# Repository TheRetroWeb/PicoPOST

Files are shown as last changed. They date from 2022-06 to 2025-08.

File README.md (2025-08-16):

# PicoPOST

> [!NOTE]
> You can get a quick summary from the blog post! [Introducing the PicoPOST - The Retro Web Blog](https://blog.theretroweb.com/2023/01/03/introducing-the-picopost/)

## Introduction

PicoPOST Logo

**PicoPOST** is a PC diagnostic card for systems with, at least, an 8-bit ISA slot. It's based around the Raspberry Pi
Pico, powered by an RP2040.

PicoPOST is designed to provide many additional benefits over the basic POST cards that are commonly available from
Chinese vendors on eBay and other sites.

This project is getting ready for public usage, with a few prototypes already in use for development purposes. More
information soon as it gets finalized.

## Implemented features

- Simple user interface, with a graphical monochrome 128x32 OLED display and a few buttons living on their own remote
  control
- Port 80h readout, with 4-place output history
- Port 90h readout, for IBM PS/2s
- Port 84h reaodut, for Compaq machines*
- Port 300h readout, for some EISA systems*
- Port 378h readout, for some Olivetti machines*
- More complete bus activity dumping facility
- Reset pulse detection
- +5V and +12V ~~and -12V~~ voltage monitor**
- Display is dimmed after 15s of inactivity to mitigate burn-in
- Flying Toasters! screensaver after 30s of inactivity on the main menu

> *: We don't have a specimen handy, so we need confirmation from someone else out there.\
> **: Negative voltages into a positive ADC is too much mental gymnastics without additional hardware

### Videos

We are slowly compiling a [YouTube playlist](https://www.youtube.com/playlist?list=PLejCJef6DKnVJob0ycztrpl9FoBufaOPA)
with a whole bunch of demonstration pieces, showing what the PicoPOST is capable of doing.\
Stay tuned for more content!

### Wishlist

New features have been implemented with the new rev 6 PCB and matching firmware.
- Full bus activity trace (HW OK, FW provisioned, but we need to make sure we are not missing data)
- Bus clock reader (HW OK, FW TBD)
- ... anything else, as long as the hardware allows it and someone implements it in firmware

## Building the firmware

### Automagically

We make use of Visual Studio Code and the official Raspberry Pi Pico extension for an easier life. When you first open
the project in VSCode, you will be prompted to install a few suggested extensions; accept the proposal and follow
on-screen instructions.

You should now be greeted by the CMake and Pi Pico sidebar panels. Use the CMake panel to switch between Debug or
Release builds, then refer to the Pico panel for building, uploading, and debugging the firmware.

It's already set up to probe for a compatible debugger via OpenOCD and gdbserver, and it works really well with our
official Raspberry Pi Debug Probe. I expect other SWD debuggers to work just as well (J-Link, STLink, ...).

### Manually

The firmware is built using the official Raspberry Pi RP2040 SDK. Follow the
[official documentation](https://github.com/raspberrypi/pico-sdk#quick-start-your-own-project) for setting it up.

The procedure is pretty straight-forward:
1. Clone the repo
   ```
   mkdir ~/repo
   cd ~/repo
   git clone https://github.com/TheRetroWeb/PicoPOST
   ```
2. Enter the repo and initialize it
   ```
   cd PicoPOST
   git submodule init
   git submodule update
   ```
3. Prepare the build system with CMake
   ```
   export PICO_SDK_PATH /path/to/pico/sdk
   cmake -DCMAKE_EXPORT_COMPILE_COMMANDS:BOOL=TRUE \
       -DCMAKE_BUILD_TYPE:STRING=Release \
       -DCMAKE_C_COMPILER:FILEPATH=/usr/bin/arm-none-eabi-gcc \
       -DCMAKE_CXX_COMPILER:FILEPATH=/usr/bin/arm-none-eabi-g++ \
       -S./firmware \
       -B./build \
       -G "Unix Makefiles"
   ```
4. Build the firmware
   ```
   cmake --build ./build --config Release --target all -j $(nproc)
   ```

### Customize the firmware

There are a couple of details you might want to tune at compile time. More specifically, you may want to better calibrate
the voltage monitor to show more accurate results.

In the primary `firmware\CMakeLists.txt` file, there are three variables you can set to skew the final ADC conversion result. These were added to account for resistor tolerances in the voltage divider circuits.
- `CALIBADJ_5V`, correction factor for the +5V rail
- `CALIBADJ_12V`, correction factor for the +12V rail

Calculating these factors is pretty straight forward:
- Install the default firmware
- Connect PicoPOST to your computer of choice with a known good power supply
- Enter `Voltage Monitor` mode
- Turn on the computer
- With a multimeter, measure the rail voltage as close as possible to PicoPOST
- Compute the required calibration factor by dividing the measured value with the one shown by PicoPOST
- Edit the `CALIBADJ` variable and build the firmware again

## Flashing the firmware

1. In order to load new firmware, the Pico must be booted into UF2 mode:
   - If the board is powered off, keep the BOOTSEL button pressed while plugging the USB cable into the Pico itself.
   - If the board is already powered, you can short the "Pico Reset" pins on the back of the card instead of removing the USB cable.
   - Alternatively, if the board is powered via USB from a PC with a data cable, you can move to the `Update FW` menu entry. By pressing Enter, the Pico will then be rebooted into UF2 mode automatically.
2. A mass storage device should be now mounted on your computer.
3. Drag and drop (or copy and paste) the `.uf2` firmware file into the device.
4. Once loaded, it will automatically restart and disconnect.
5. If all went well, you should now be greeted by the main menu on the OLED display.\
   You can verify the current firmware version by entering the `Info` page.

## Interested in helping?
- Submit issues and pull requests!
- Join us in the #picopost channel in [The Retro Web discord server](https://discord.gg/TdD4tqQ7fv)
- Join us and other developers of retro Pico hardware (such as PicoGUS and PicoMEM) in the [Retro Pico Hardware discord server](https://discord.gg/QBUkpPqFa5)

## Directories

```
datasheets/  Reference documentation for components used in the PicoPOST
firmware/    Source code for the PicoPOST firmware (written in C/C++ with the official Pico SDK)
pcb/         KiCad schematics and PCB design files
```

## License

The firmware portion of PicoPOST is licensed under the MIT license.\
The hardware portion of PicoPOST is licensed under the CERN OHL v2 Permissive license.

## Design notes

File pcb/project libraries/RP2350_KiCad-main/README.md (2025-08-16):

# RP2350_KiCad
Symbols, Footprints &amp; Models for the RP2350

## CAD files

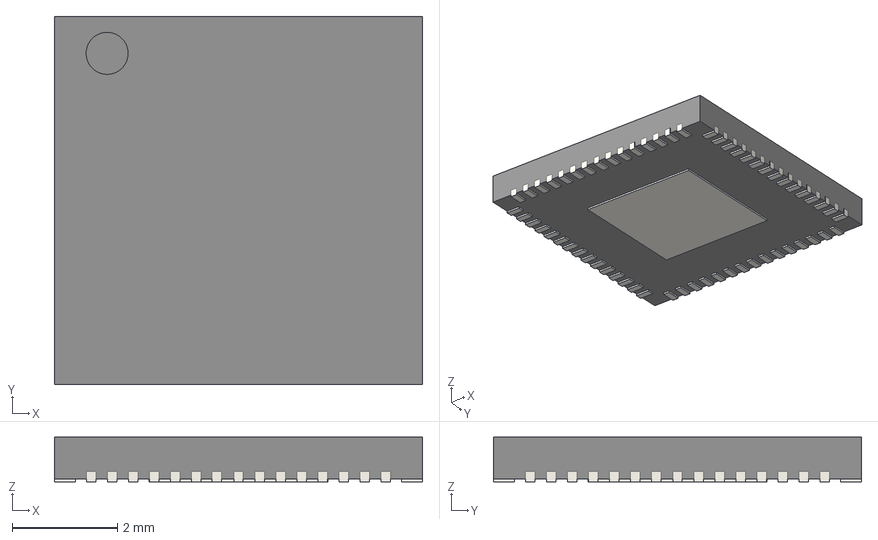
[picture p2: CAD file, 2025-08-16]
pcb/project libraries/RP2350_KiCad-main/RP2350A-QFN60.step
7.00 x 7.00 x 0.85 mm

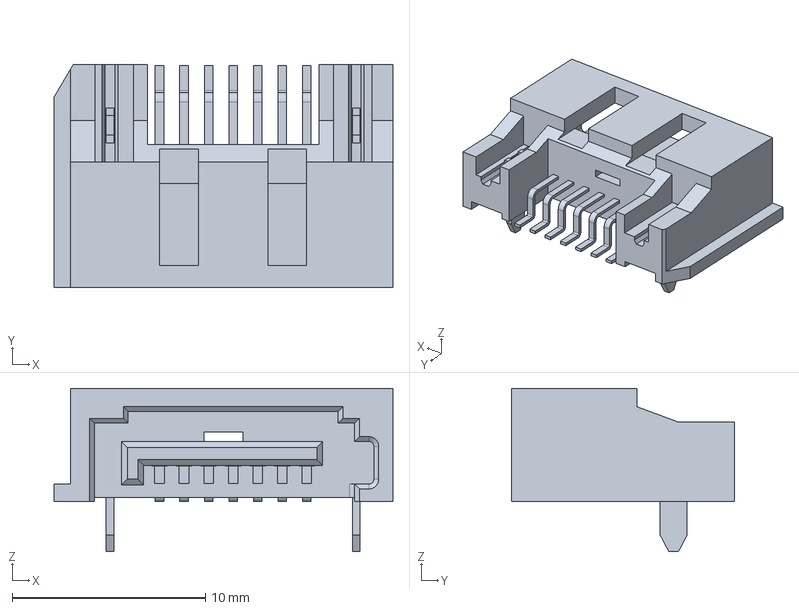
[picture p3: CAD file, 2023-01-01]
pcb/project libraries/eec.models/Molex_-_47080-4001.step
17.5 x 11.6 x 8.45 mm

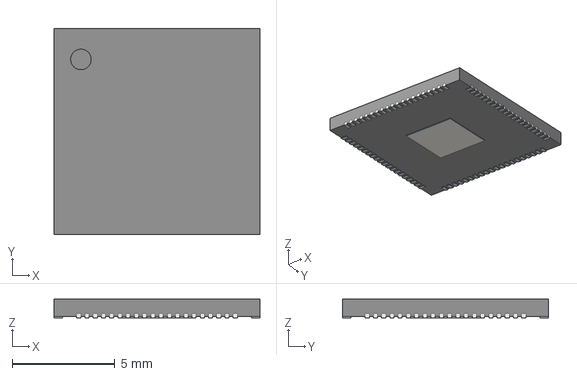
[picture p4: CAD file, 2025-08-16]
pcb/project libraries/RP2350_KiCad-main/RP2350B-QFN80.step
10.0 x 10.0 x 0.9 mm

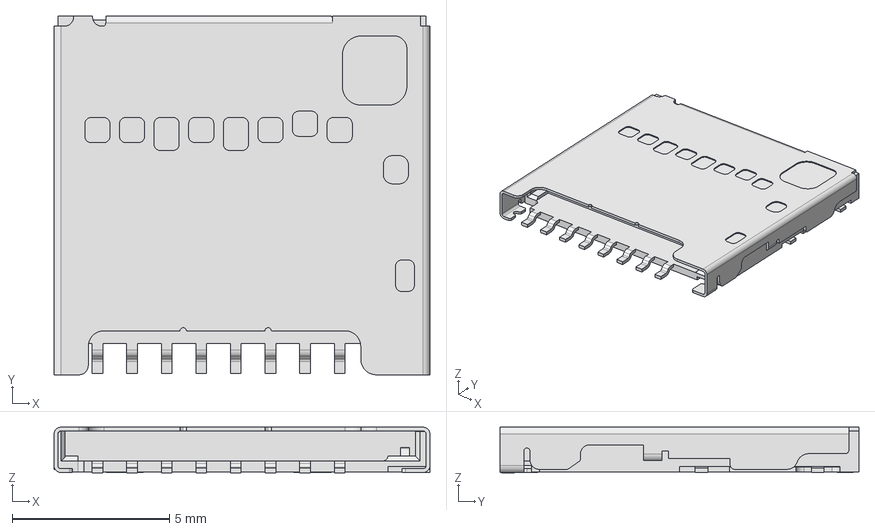
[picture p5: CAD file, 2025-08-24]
pcb/project libraries/1040310811.stp
11.9 x 11.4 x 1.45 mm

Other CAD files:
pcb/project libraries/eec.models/470804001.stp

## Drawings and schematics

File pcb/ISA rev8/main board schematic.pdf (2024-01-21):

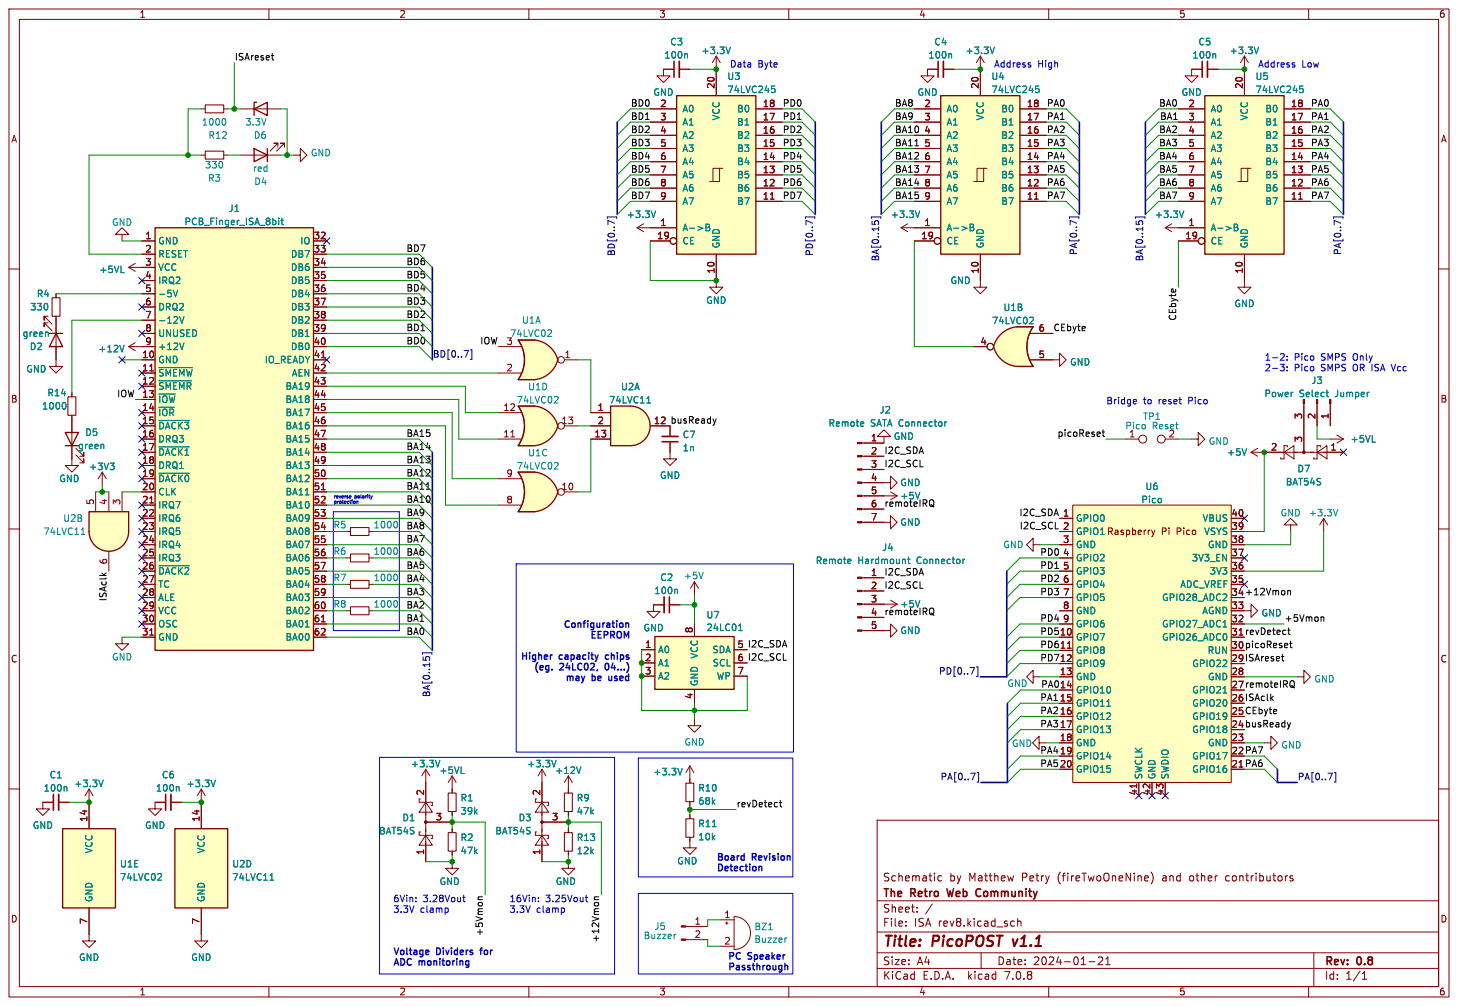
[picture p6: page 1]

J3 Power Select Jumper GND

Bridge to reset Pico Configuration EEPROM

J2 Remote SATA Connector GND GNDGND

Higher capacity chips
(eg. 24LC02, 04...) may be used

4 SDA 5 SCL 6 WP 7 VCC

Passthrough Board Revision Detection

Voltage Dividers for ADC monitoring

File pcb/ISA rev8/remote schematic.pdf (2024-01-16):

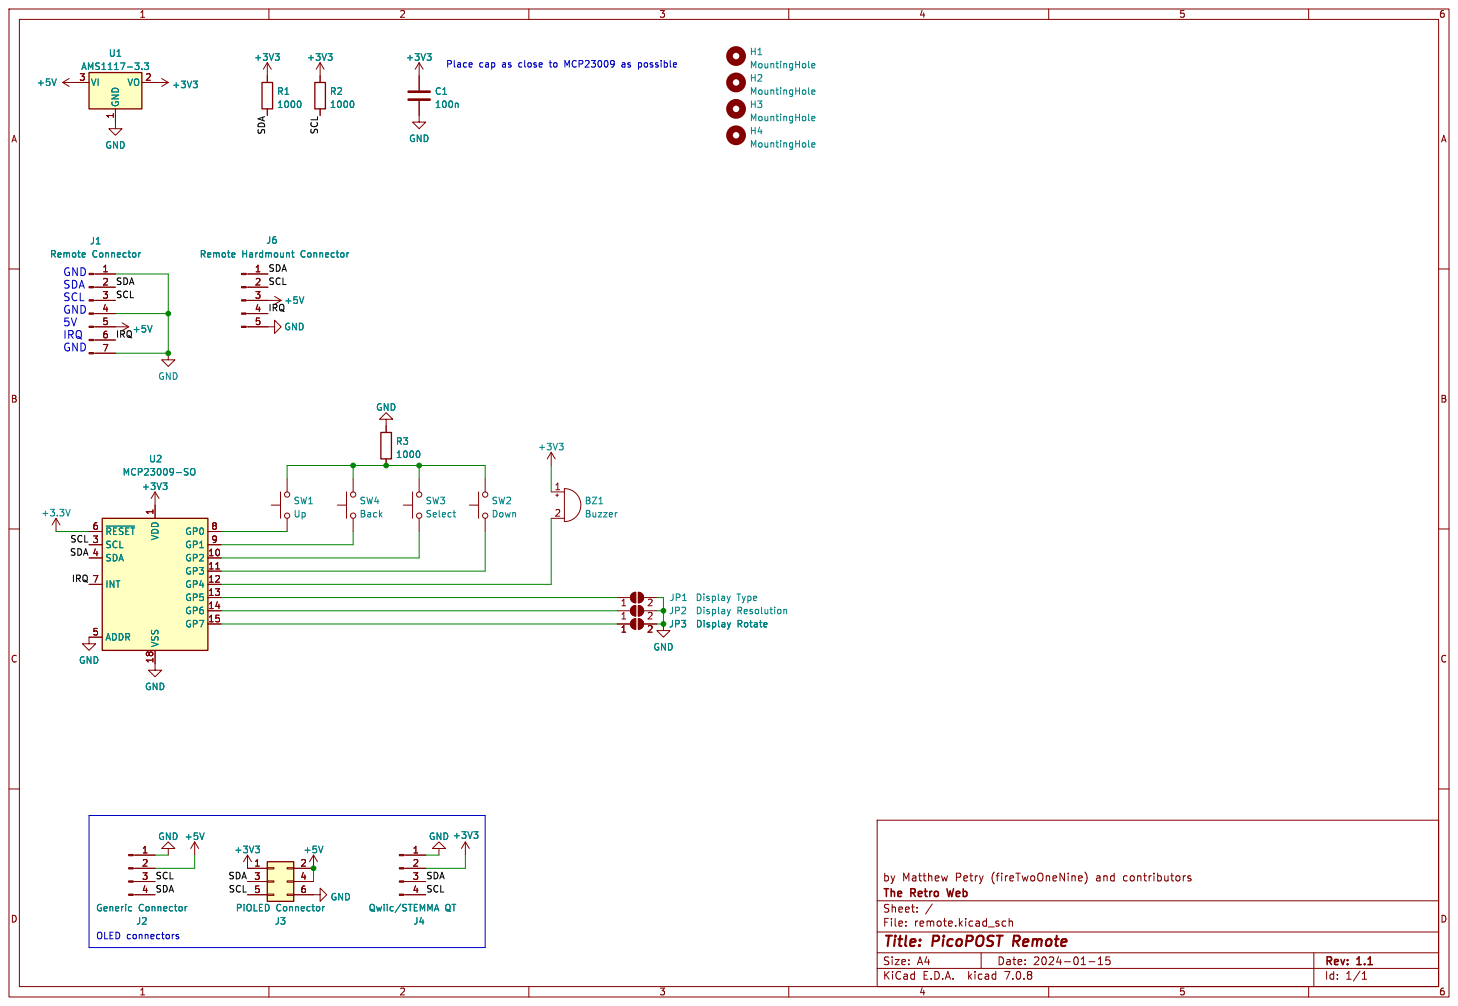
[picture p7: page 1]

1 VO 2 VI 3 U1 AMS1117-3.3 +5V GND GND

Place cap as close to MCP23009 as possible

1 GP2 10 GP3 11 GP4 12 GP5 13 GP6 14 GP7 15 VSS 18 SCL 3 SDA 4 ADDR 5 ~{RESET} 6

Id: 1/1 Title: PicoPOST Remote

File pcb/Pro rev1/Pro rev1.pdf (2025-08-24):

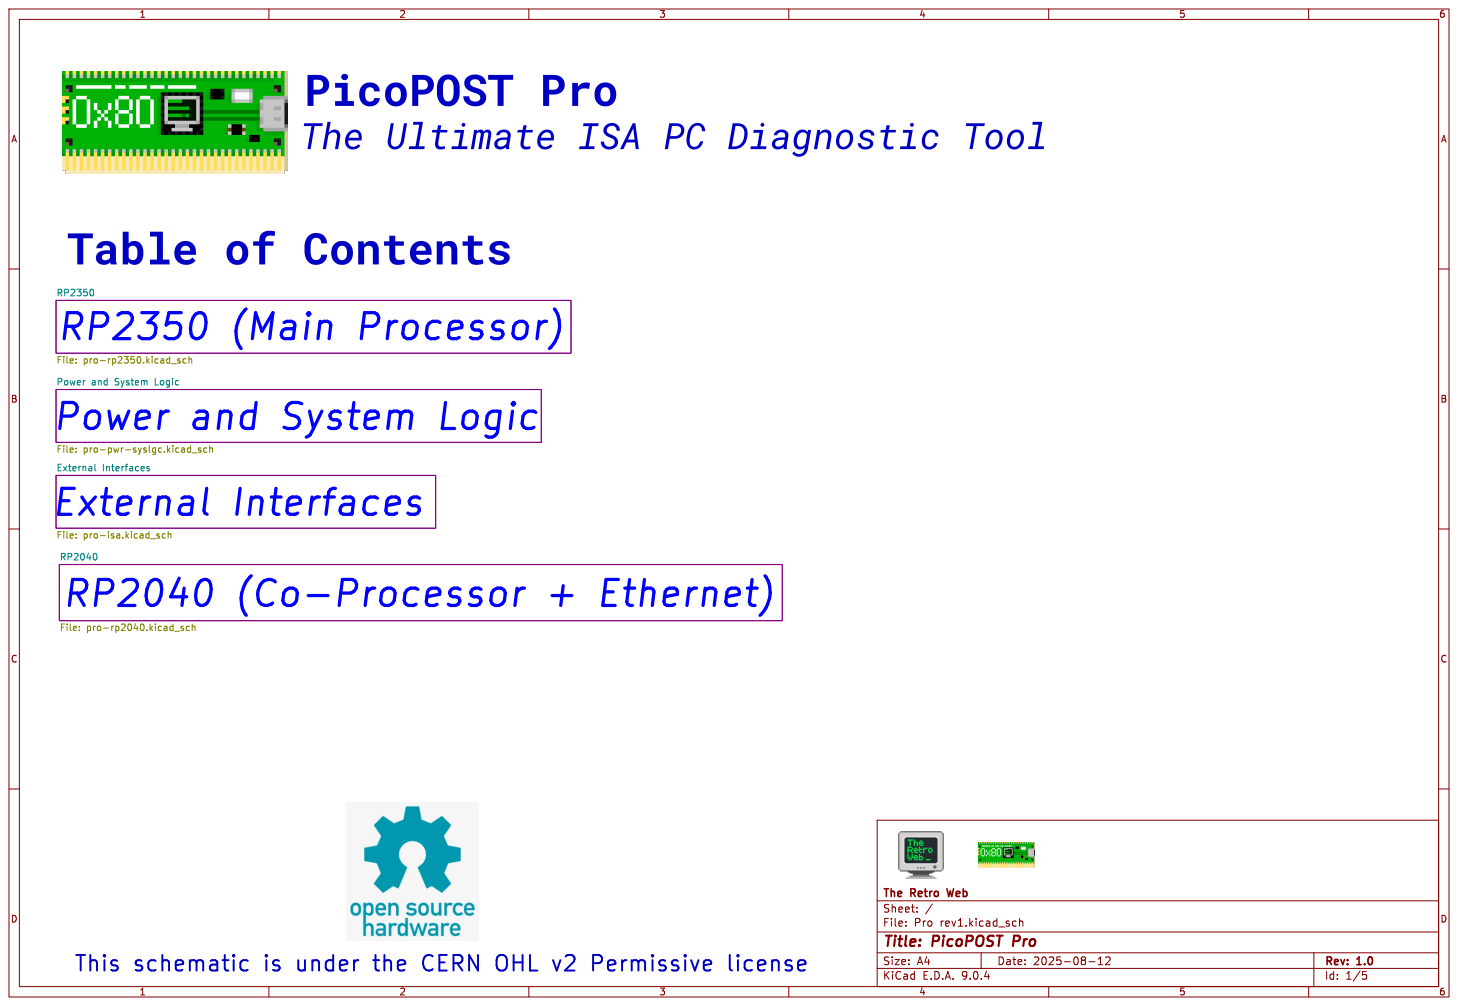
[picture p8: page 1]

Power and System Logic File: pro-pwr-syslgc.kicad_sch
Power and System Logic

External Interfaces File: pro-isa.kicad_sch
External Interfaces

Id: 1/5 Title: PicoPOST Pro

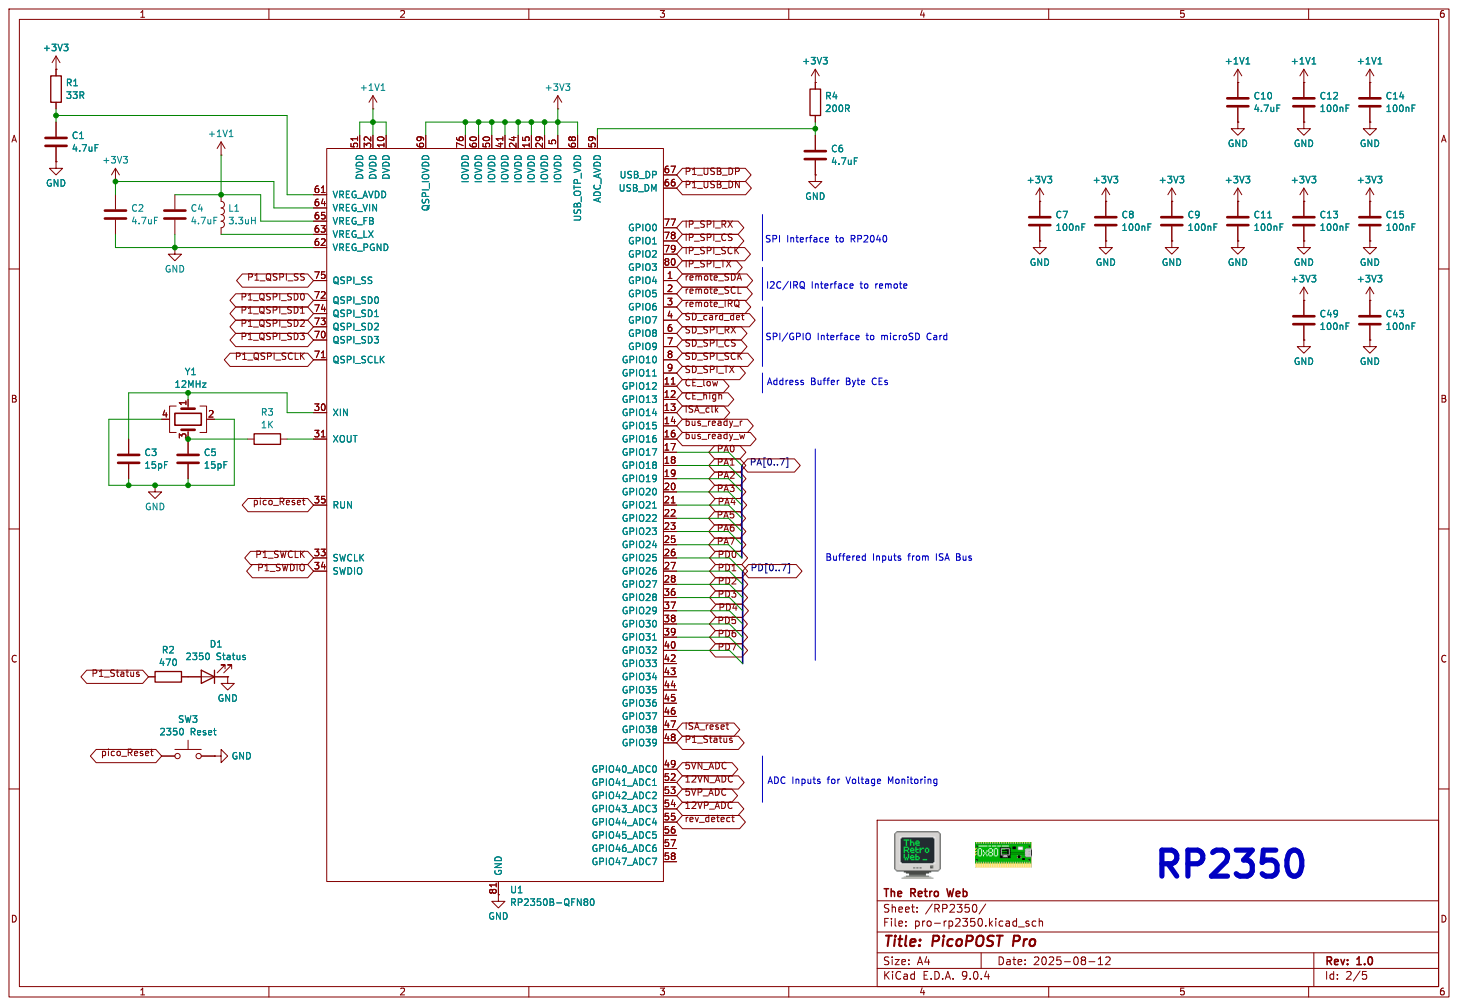
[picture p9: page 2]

Id: 2/5 Title: PicoPOST Pro

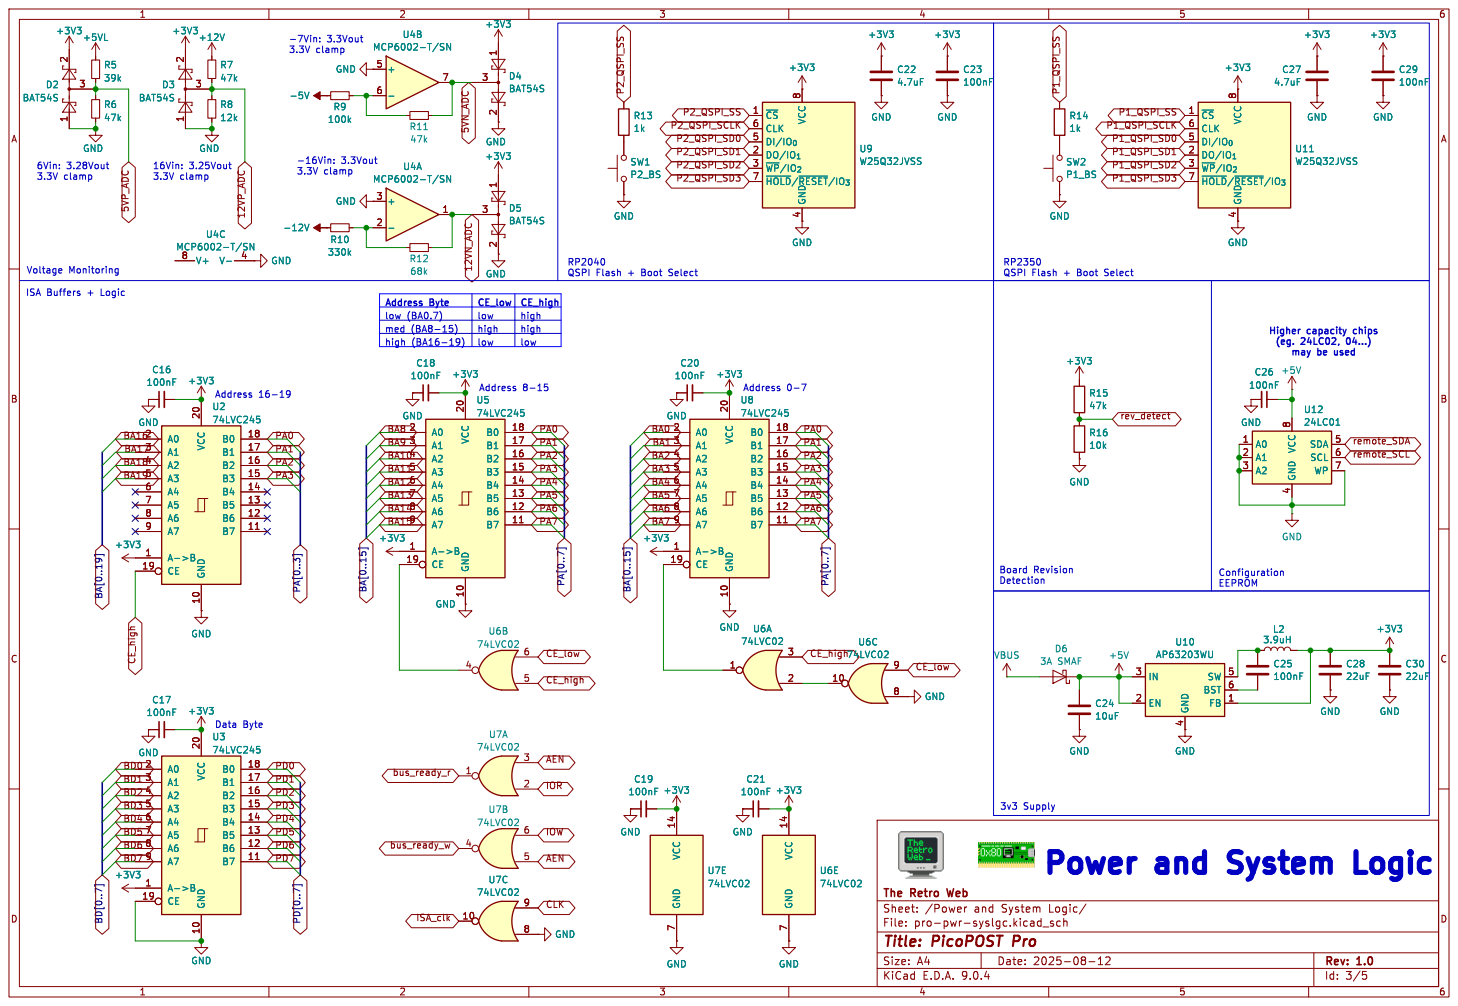
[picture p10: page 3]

Id: 3/5 Title: PicoPOST Pro

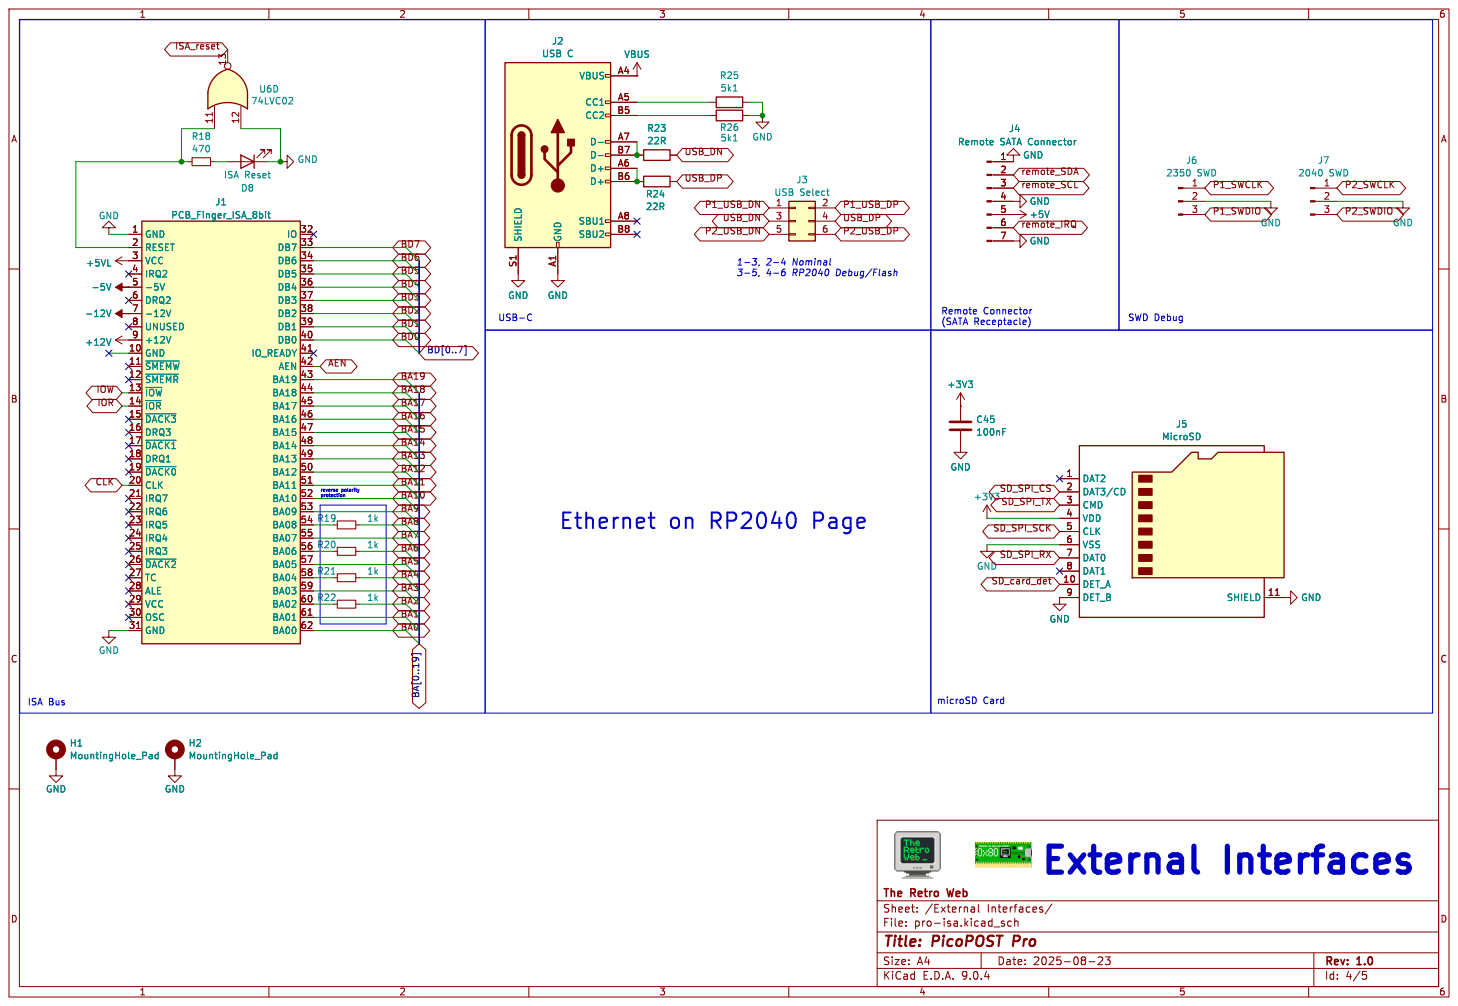
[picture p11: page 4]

Id: 4/5 Title: PicoPOST Pro

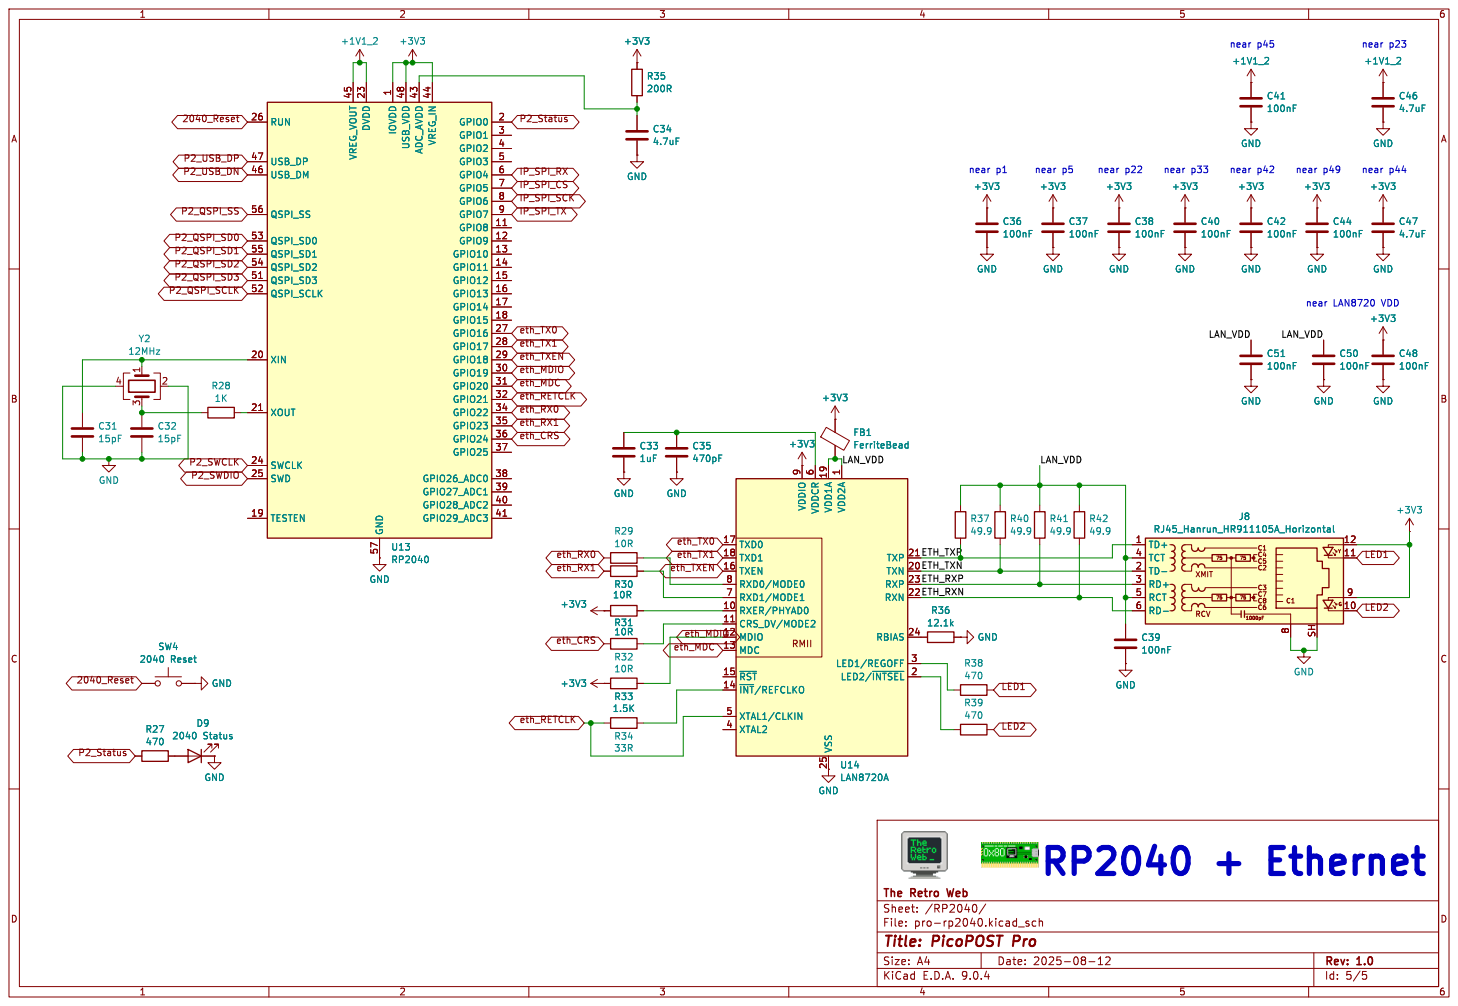
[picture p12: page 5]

1 TXP 21 TXN 20 RXP 23 RXN 22 RBIAS 24

J8 RJ45_Hanrun_HR911105A_Horizontal TD+ 1 TCT 4 TD- 2 RD+ 3 RCT 5 RD- 6

YG TD+ 1 TCT 4 TD- 2 RD+ 3 RCT 5 RD- 6

Id: 5/5 Title: PicoPOST Pro

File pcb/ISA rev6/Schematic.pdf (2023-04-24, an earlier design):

GND | GND
1000 | R5 | 1000

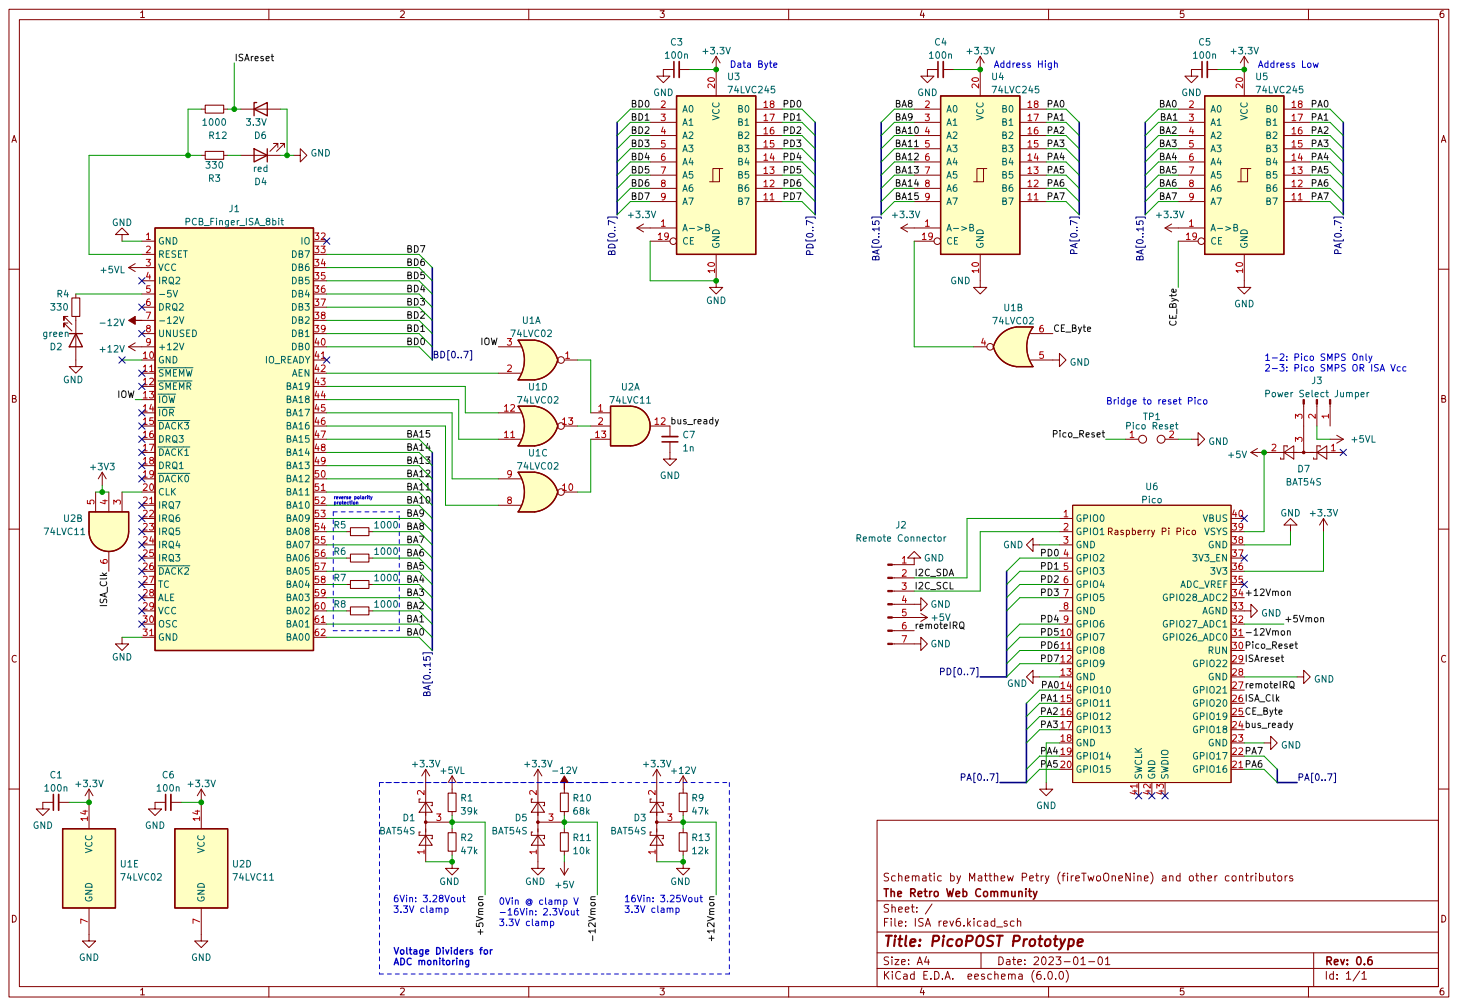
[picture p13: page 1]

1-2: Pico SMPS Only 2-3: Pico SMPS OR ISA Vcc Address Low

BA6 BA7 PD[0..7] ISA_Clk
IRQ3 25 ~{DACK2} 26 TC 27 ALE 28 VCC 29 VCC 3 OSC 30 GND 31

Bridge to reset Pico

File: ISA rev6.kicad_sch Sheet: / The Retro Web Community

Id: 1/1 Title: PicoPOST Prototype

1000 | SW4 Back
100n GND | GND

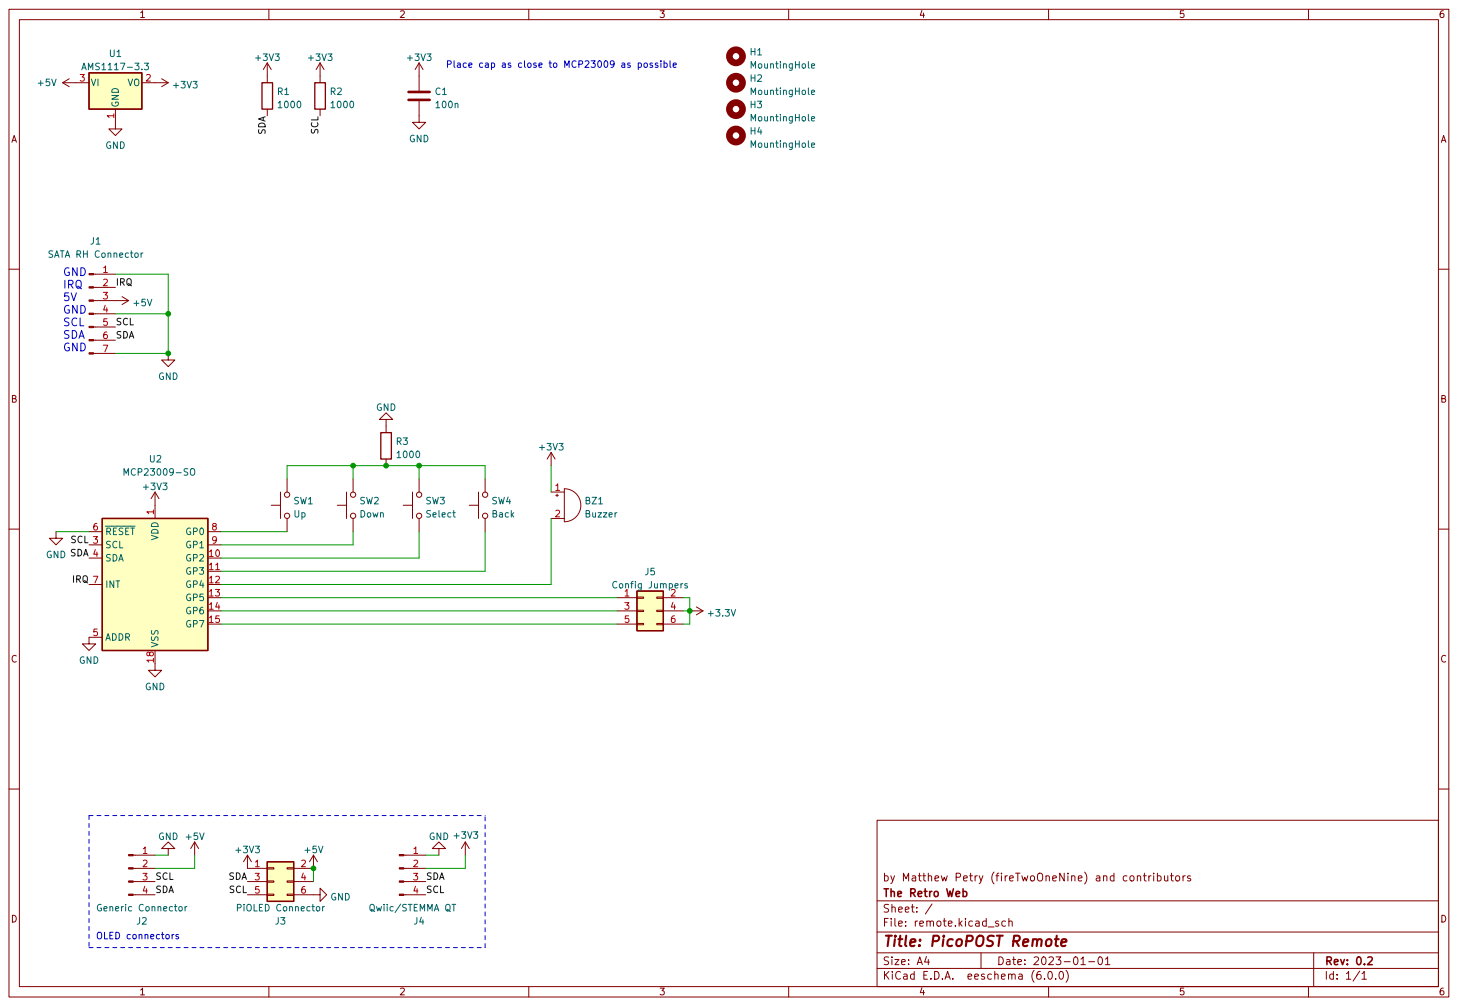
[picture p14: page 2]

1 VO 2 VI 3 U1 AMS1117-3.3 GND
Place cap as close to MCP23009 as possible GND

1 GP2 10 GP3 11 GP4 12 GP5 13 GP6 14 GP7 15 VSS 18 SCL 3 SDA 4 ADDR 5 ~{RESET} 6

by Matthew Petry (fireTwoOneNine) and contributors
File: remote.kicad_sch Sheet: / The Retro Web

Id: 1/1 Title: PicoPOST Remote

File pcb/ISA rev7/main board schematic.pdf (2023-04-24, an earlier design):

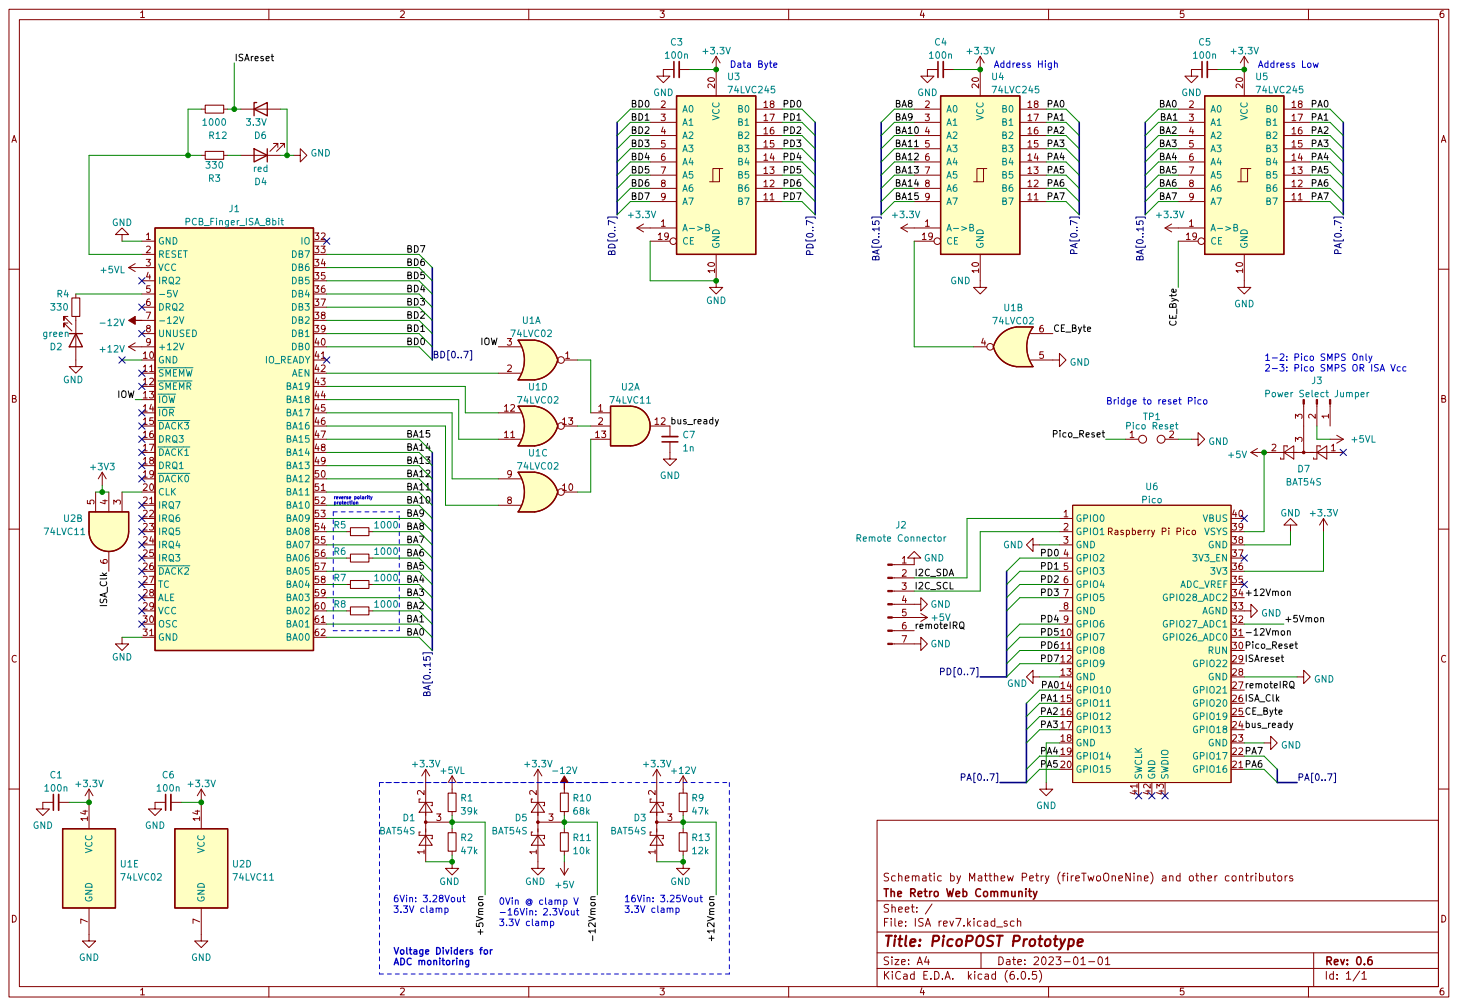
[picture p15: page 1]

Bridge to reset Pico

Schematic by Matthew Petry (fireTwoOneNine) and other contributors GND GND

1 2 D1 3 BAT54S GND GND VCC 14 GND

File: ISA rev7.kicad_sch Sheet: / The Retro Web Community

Id: 1/1 Title: PicoPOST Prototype

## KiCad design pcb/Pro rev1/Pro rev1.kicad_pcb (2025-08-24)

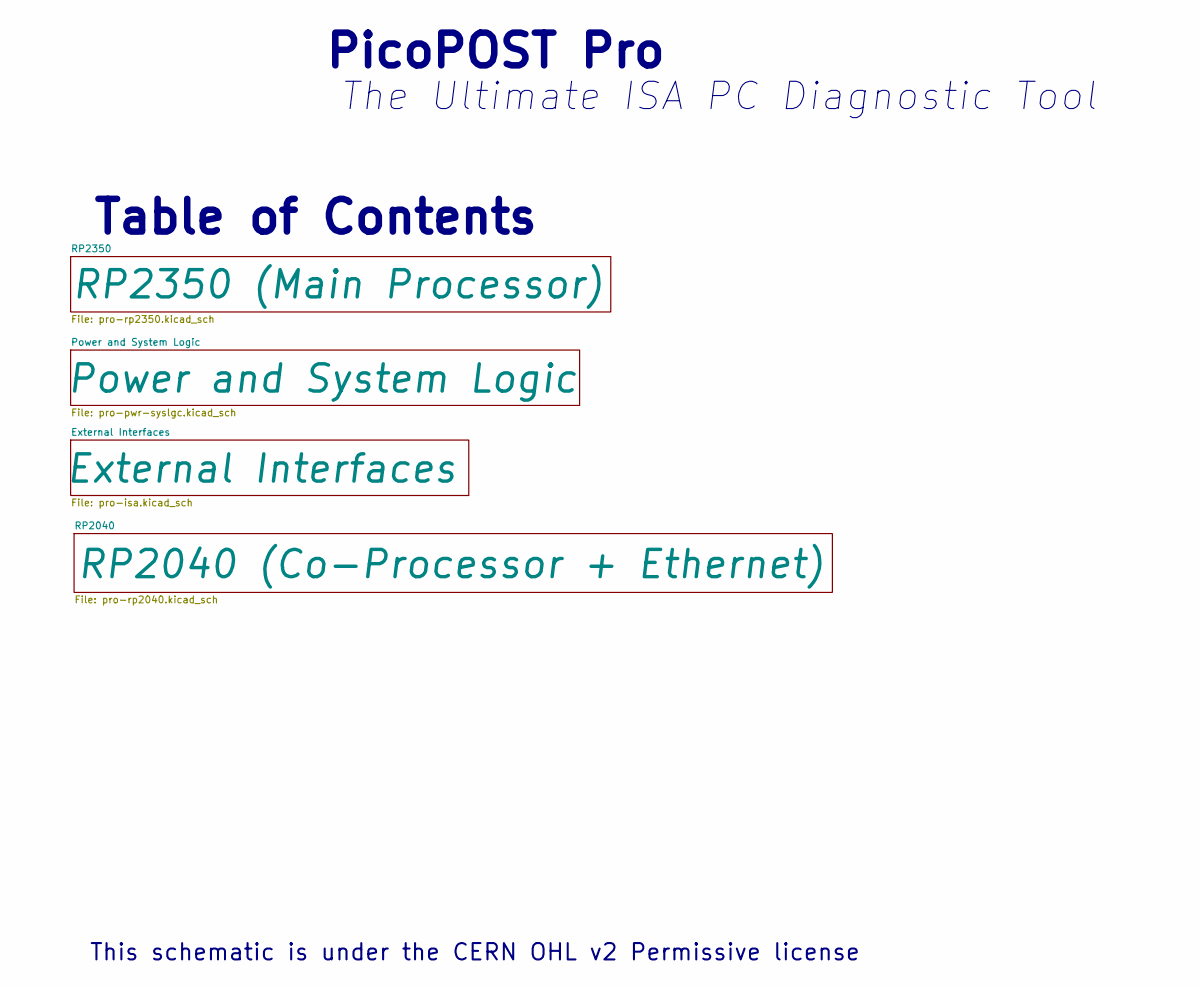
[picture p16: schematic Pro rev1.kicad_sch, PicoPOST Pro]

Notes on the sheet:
The Ultimate ISA PC Diagnostic Tool
This schematic is under the CERN OHL v2 Permissive license
PicoPOST Pro
Table of Contents

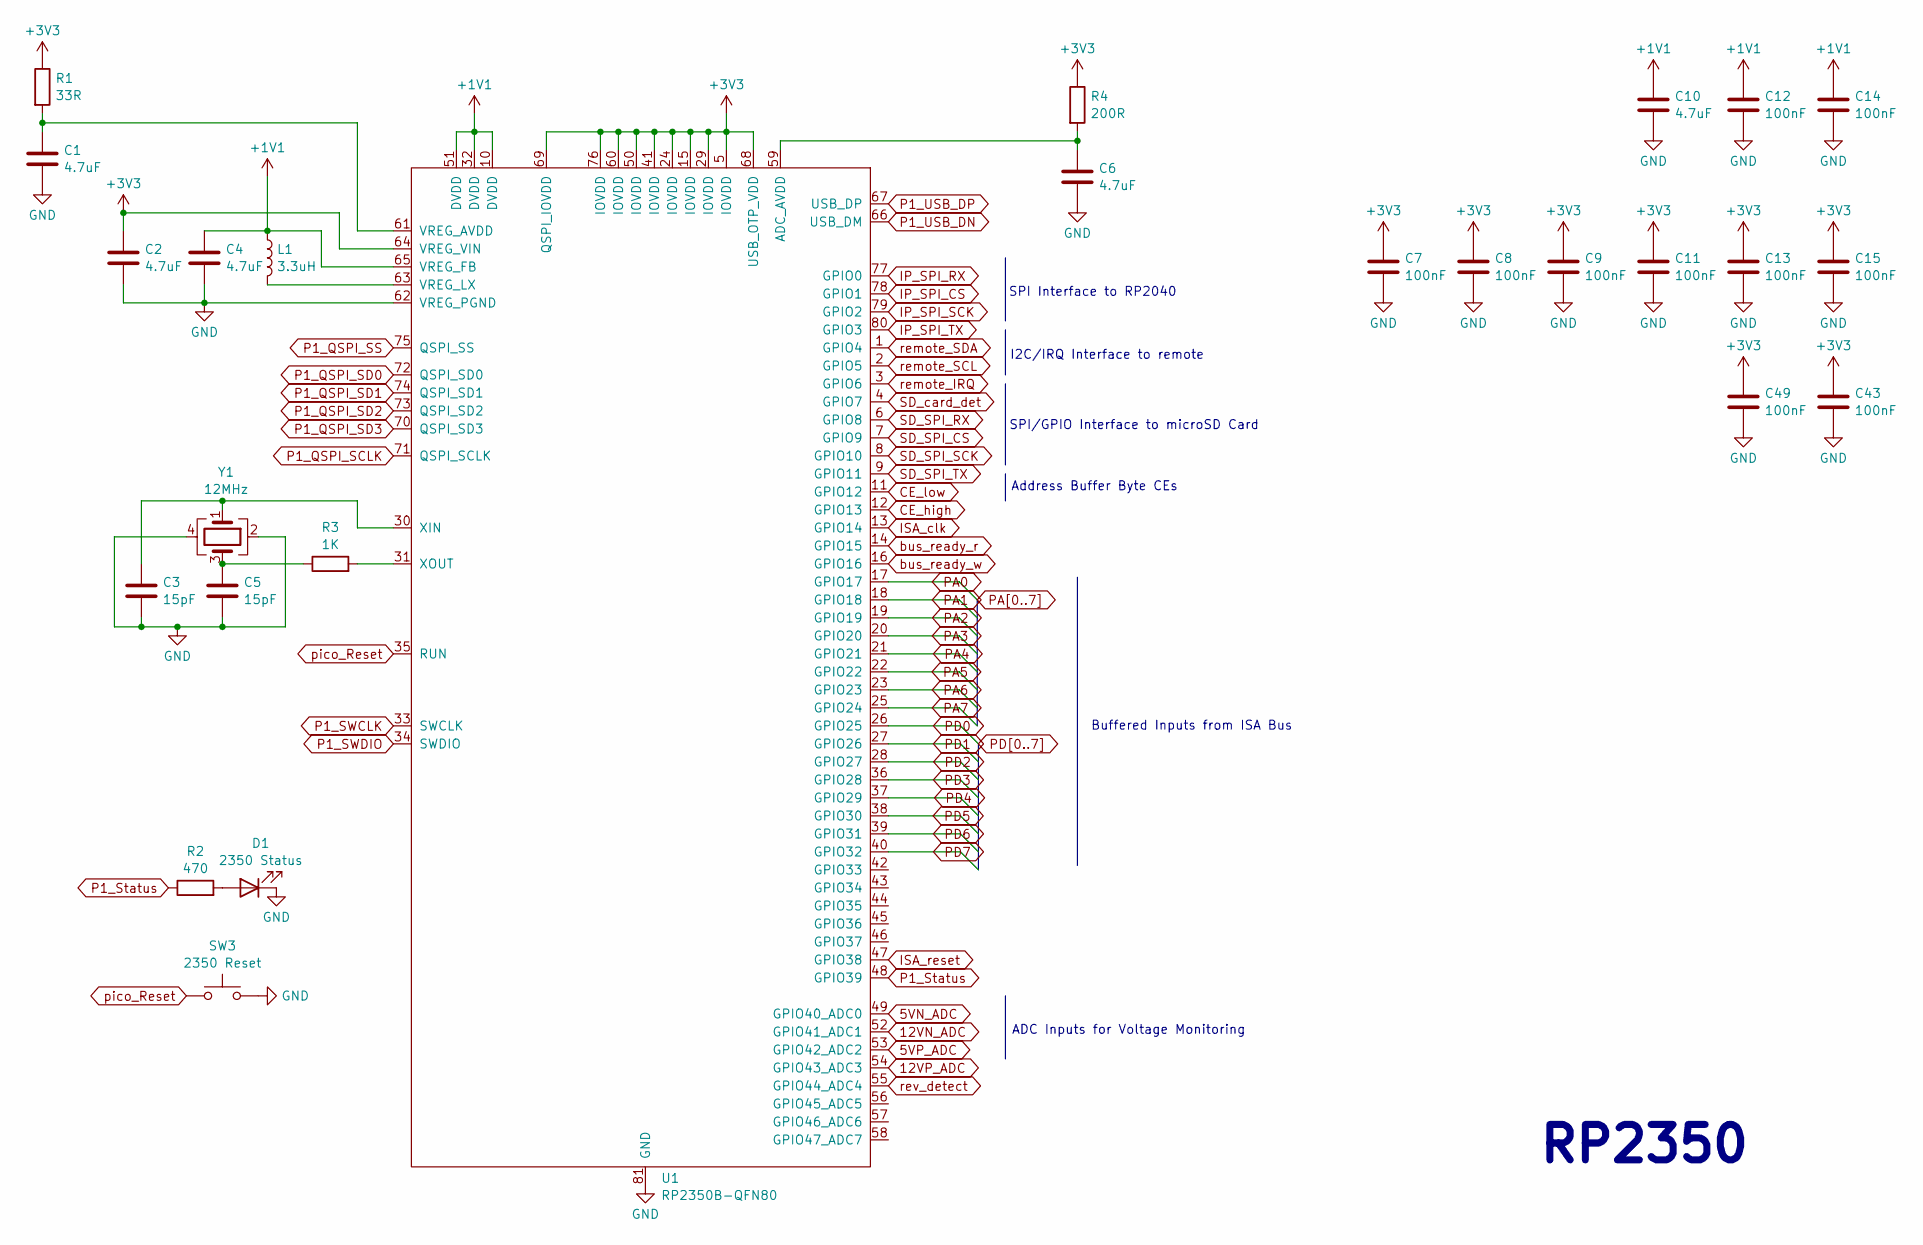
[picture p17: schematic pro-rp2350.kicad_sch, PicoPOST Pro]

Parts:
C1, C2, C4: 4.7uF; C_0402_1005Metric
C3, C5: 15pF; C_0402_1005Metric
C6, C10: 4.7uF; C_0603_1608Metric
C7, C8, C9, C11, C12, C13, C14, C15, C43, C49: 100nF; C_0402_1005Metric
D1: 2350 Status; LED_0805_2012Metric
L1: 3.3uH; L_Sunlord_SWPA4030S
R1: 33R; R_0402_1005Metric
R2: 470; R_0603_1608Metric
R3: 1K; R_0402_1005Metric
R4: 200R; R_0402_1005Metric
SW3: 2350 Reset; SW_SPST_TS-1088-xR020
U1: RP2350B-QFN80; RP2350B_QFN-80_EP_10.573x10.573_Pitch0.4mm
Y1: 12MHz; Crystal_SMD_Abracon_ABM8G-4Pin_3.2x2.5mm

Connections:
5VN_ADC: U1.49 (GPIO40_ADC0); also elsewhere on the board
5VP_ADC: U1.53 (GPIO42_ADC2); also elsewhere on the board
12VN_ADC: U1.52 (GPIO41_ADC1); also elsewhere on the board
12VP_ADC: U1.54 (GPIO43_ADC3); also elsewhere on the board
+1V1: C4.1, C10.1, C12.1, C14.1, L1.1, U1.10 (DVDD), U1.32 (DVDD), U1.51 (DVDD), U1.65 (VREG_FB)
+3V3: C2.1, C7.1, C8.1, C9.1, C11.1, C13.1, C15.1, C43.1, C49.1, R1.1, R4.1, U1.5 (IOVDD), U1.15 (IOVDD), U1.24 (IOVDD), U1.29 (IOVDD), U1.41 (IOVDD), U1.50 (IOVDD), U1.60 (IOVDD), U1.64 (VREG_VIN), U1.68 (USB_OTP_VDD), U1.69 (QSPI_IOVDD), U1.76 (IOVDD); also elsewhere on the board
CE_high: U1.12 (GPIO13); also elsewhere on the board
CE_low: U1.11 (GPIO12); also elsewhere on the board
GND: C1.2, C2.2, C3.1, C4.2, C5.2, C6.2, C7.2, C8.2, C9.2, C10.2, C11.2, C12.2, C13.2, C14.2, C15.2, C43.2, C49.2, D1.1 (K), SW3.2, U1.62 (VREG_PGND), U1.81 (GND), Y1.2, Y1.4; also elsewhere on the board
IP_SPI_CS: U1.78 (GPIO1); also elsewhere on the board
IP_SPI_RX: U1.77 (GPIO0); also elsewhere on the board
IP_SPI_SCK: U1.79 (GPIO2); also elsewhere on the board
IP_SPI_TX: U1.80 (GPIO3); also elsewhere on the board
ISA_clk: U1.13 (GPIO14); also elsewhere on the board
ISA_reset: U1.47 (GPIO38); also elsewhere on the board
unnamed: C5.1, R3.1, Y1.3
unnamed: D1.2 (A), R2.2
unnamed: C6.1, R4.2, U1.59 (ADC_AVDD)
unnamed: C1.1, R1.2, U1.61 (VREG_AVDD)
unnamed: L1.2, U1.63 (VREG_LX)
unnamed: C3.2, U1.30 (XIN), Y1.1
unnamed: R3.2, U1.31 (XOUT)
P1_QSPI_SCLK: U1.71 (QSPI_SCLK); also elsewhere on the board
P1_QSPI_SD0: U1.72 (QSPI_SD0); also elsewhere on the board
P1_QSPI_SD1: U1.74 (QSPI_SD1); also elsewhere on the board
P1_QSPI_SD2: U1.73 (QSPI_SD2); also elsewhere on the board
P1_QSPI_SD3: U1.70 (QSPI_SD3); also elsewhere on the board
P1_QSPI_SS: U1.75 (QSPI_SS); also elsewhere on the board
P1_SWCLK: U1.33 (SWCLK); also elsewhere on the board
P1_SWDIO: U1.34 (SWDIO); also elsewhere on the board
P1_Status: R2.1, U1.48 (GPIO39)
P1_USB_DN: U1.66 (USB_DM); also elsewhere on the board
P1_USB_DP: U1.67 (USB_DP); also elsewhere on the board
PA0: U1.17 (GPIO17); also elsewhere on the board
PA1: U1.18 (GPIO18); also elsewhere on the board
PA2: U1.19 (GPIO19); also elsewhere on the board
PA3: U1.20 (GPIO20); also elsewhere on the board
PA4: U1.21 (GPIO21); also elsewhere on the board
PA5: U1.22 (GPIO22); also elsewhere on the board
PA6: U1.23 (GPIO23); also elsewhere on the board
PA7: U1.25 (GPIO24); also elsewhere on the board
PD0: U1.26 (GPIO25); also elsewhere on the board
PD1: U1.27 (GPIO26); also elsewhere on the board
PD2: U1.28 (GPIO27); also elsewhere on the board
PD3: U1.36 (GPIO28); also elsewhere on the board
PD4: U1.37 (GPIO29); also elsewhere on the board
PD5: U1.38 (GPIO30); also elsewhere on the board
PD6: U1.39 (GPIO31); also elsewhere on the board
PD7: U1.40 (GPIO32); also elsewhere on the board
SD_SPI_CS: U1.7 (GPIO9); also elsewhere on the board
SD_SPI_RX: U1.6 (GPIO8); also elsewhere on the board
SD_SPI_SCK: U1.8 (GPIO10); also elsewhere on the board
SD_SPI_TX: U1.9 (GPIO11); also elsewhere on the board
SD_card_det: U1.4 (GPIO7); also elsewhere on the board
bus_ready_r: U1.14 (GPIO15); also elsewhere on the board
bus_ready_w: U1.16 (GPIO16); also elsewhere on the board
pico_Reset: SW3.1, U1.35 (RUN)
remote_IRQ: U1.3 (GPIO6); also elsewhere on the board
remote_SCL: U1.2 (GPIO5); also elsewhere on the board
remote_SDA: U1.1 (GPIO4); also elsewhere on the board
rev_detect: U1.55 (GPIO44_ADC4); also elsewhere on the board

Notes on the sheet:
SPI/GPIO Interface to microSD Card
I2C/IRQ Interface to remote
Buffered Inputs from ISA Bus
SPI Interface to RP2040
Address Buffer Byte CEs
ADC Inputs for Voltage Monitoring
RP2350

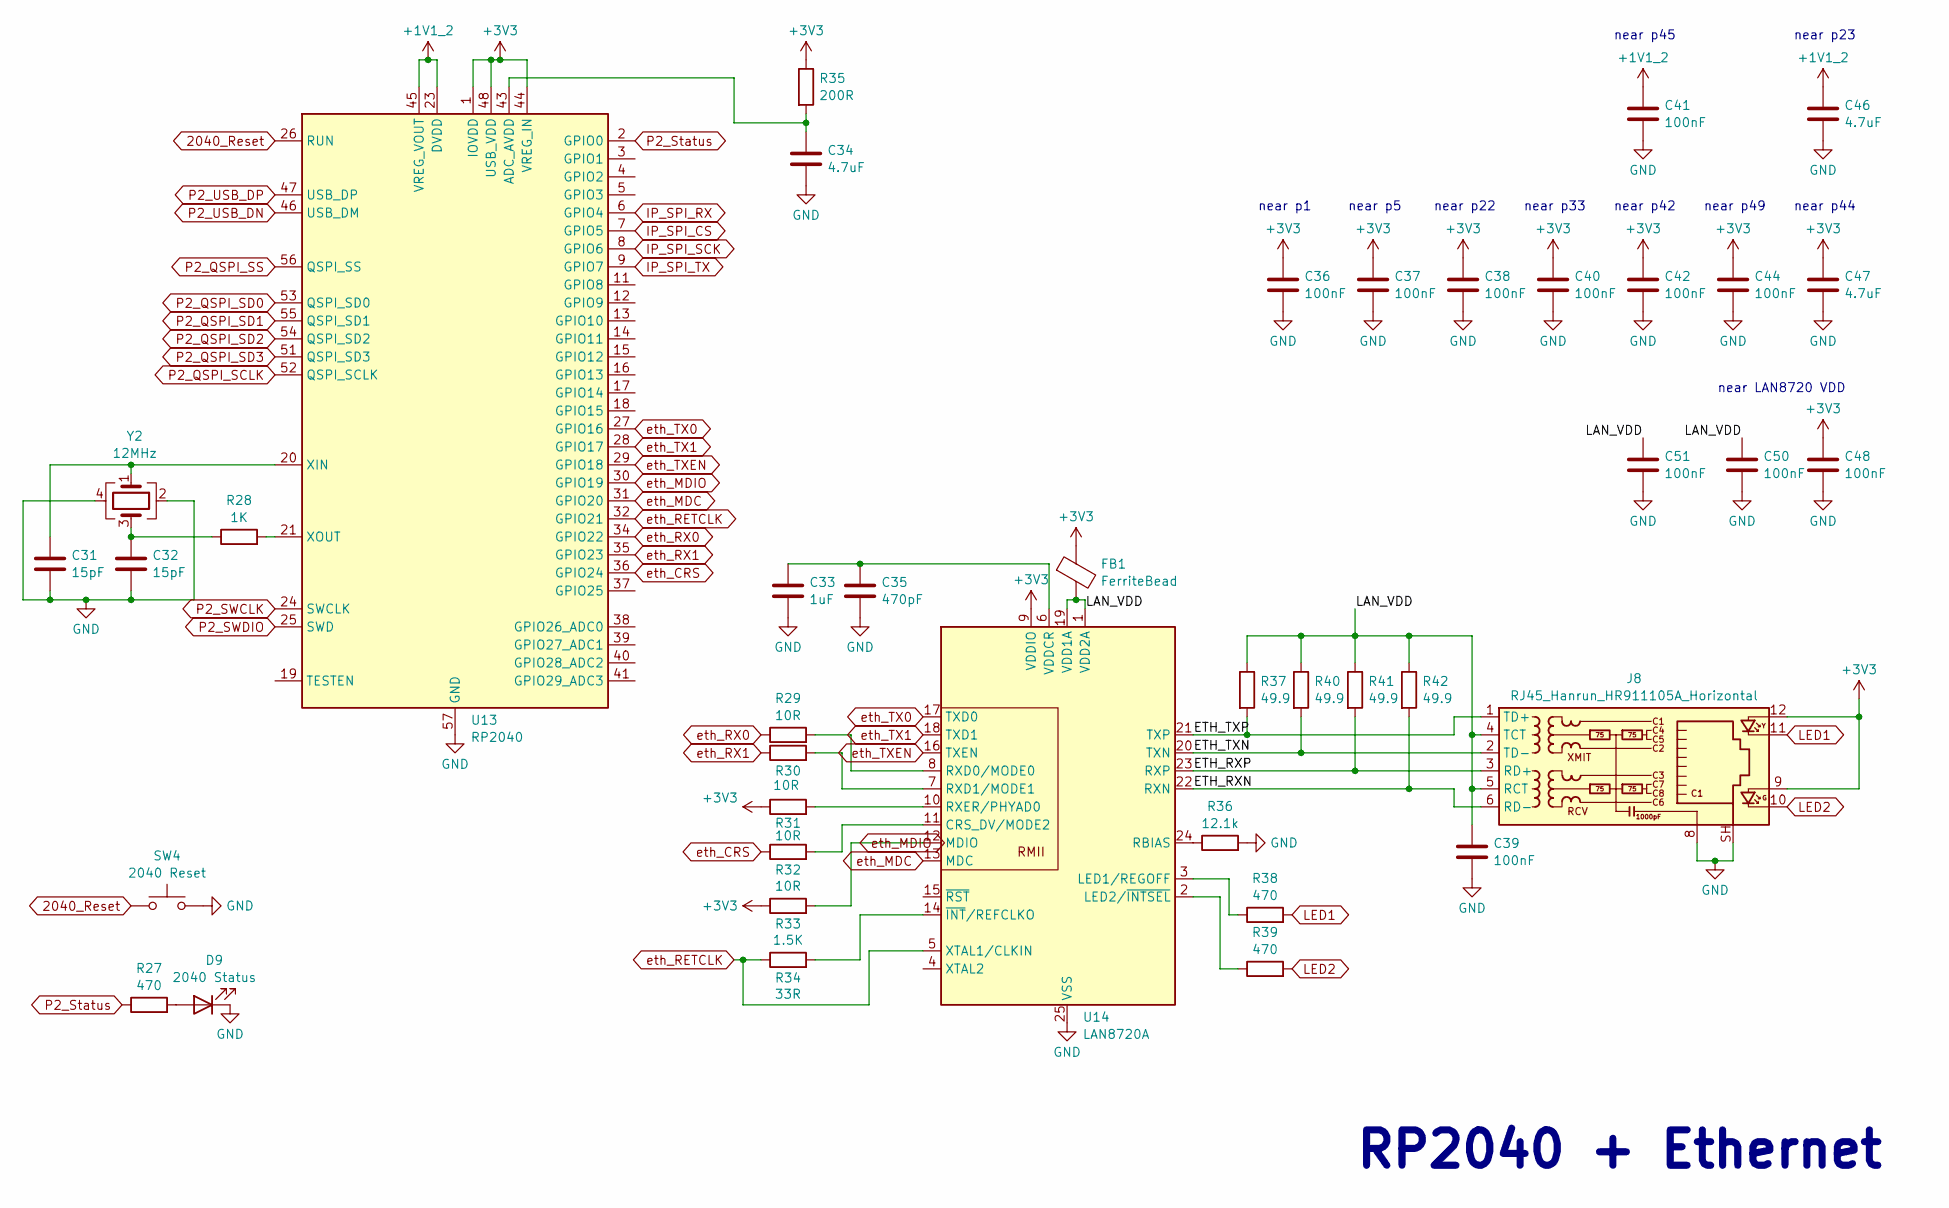
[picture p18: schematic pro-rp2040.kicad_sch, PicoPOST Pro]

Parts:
C31, C32: 15pF; C_0402_1005Metric
C33: 1uF; C_0603_1608Metric
C34, C46, C47: 4.7uF; C_0603_1608Metric
C35: 470pF; C_0603_1608Metric
C36, C37, C38, C39, C40, C41, C42, C44, C48, C50, C51: 100nF; C_0402_1005Metric
D9: 2040 Status; LED_0805_2012Metric
FB1: FerriteBead; L_0603_1608Metric
J8: RJ45_Hanrun_HR911105A_Horizontal
R27, R38, R39: 470; R_0603_1608Metric
R28: 1K; R_0402_1005Metric
R29, R30, R31, R32: 10R; R_0402_1005Metric
R33: 1.5K; R_0402_1005Metric
R34: 33R; R_0402_1005Metric
R35: 200R; R_0402_1005Metric
R36: 12.1k; R_0402_1005Metric
R37, R40, R41, R42: 49.9; R_0603_1608Metric
SW4: 2040 Reset; SW_SPST_TS-1088-xR020
U13: RP2040; QFN-56-1EP_7x7mm_P0.4mm_EP3.2x3.2mm
U14: LAN8720A; VQFN-24-1EP_4x4mm_P0.5mm_EP2.5x2.5mm_ThermalVias
Y2: 12MHz; Crystal_SMD_Abracon_ABM8G-4Pin_3.2x2.5mm

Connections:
2040_Reset: SW4.1, U13.26 (RUN)
+1V1_2: C41.1, C46.1, U13.23 (DVDD), U13.45 (VREG_VOUT), U13.50 (DVDD)
+3V3: C36.1, C37.1, C38.1, C40.1, C42.1, C44.1, C47.1, C48.1, FB1.1, J8.9, J8.12, R31.1, R33.1, R35.1, U13.1 (IOVDD), U13.10 (IOVDD), U13.22 (IOVDD), U13.33 (IOVDD), U13.42 (IOVDD), U13.44 (VREG_IN), U13.48 (USB_VDD), U13.49 (IOVDD), U14.9 (VDDIO); also elsewhere on the board
/RP2040/ETH_RXN: J8.6 (RD-), R42.2, U14.22 (RXN)
/RP2040/ETH_RXP: J8.3 (RD+), R41.2, U14.23 (RXP)
/RP2040/ETH_TXN: J8.2 (TD-), R40.2, U14.20 (TXN)
/RP2040/ETH_TXP: J8.1 (TD+), R37.2, U14.21 (TXP)
/RP2040/LAN_VDD: C39.1, C50.1, C51.1, FB1.2, J8.4 (TCT), J8.5 (RCT), R37.1, R40.1, R41.1, R42.1, U14.1 (VDD2A), U14.19 (VDD1A)
GND: C31.1, C32.2, C33.2, C34.2, C35.2, C36.2, C37.2, C38.2, C39.2, C40.2, C41.2, C42.2, C44.2, C46.2, C47.2, C48.2, C50.2, C51.2, D9.1 (K), J8.8, J8.SH, R36.2, SW4.2, U13.57 (GND), U14.25 (VSS), Y2.2, Y2.4; also elsewhere on the board
IP_SPI_CS: U13.7 (GPIO5); also elsewhere on the board
IP_SPI_RX: U13.6 (GPIO4); also elsewhere on the board
IP_SPI_SCK: U13.8 (GPIO6); also elsewhere on the board
IP_SPI_TX: U13.9 (GPIO7); also elsewhere on the board
LED1: J8.11, R38.2
LED2: J8.10, R39.2
unnamed: C32.1, R28.1, Y2.3
unnamed: D9.2 (A), R27.2
unnamed: C34.1, R35.2, U13.43 (ADC_AVDD)
unnamed: C31.2, U13.20 (XIN), Y2.1
unnamed: R28.2, U13.21 (XOUT)
unnamed: R32.2, U14.11 (CRS_DV/MODE2)
unnamed: R38.1, U14.3 (LED1/REGOFF)
unnamed: R39.1, U14.2 (LED2/~INTSEL)
unnamed: R36.1, U14.24 (RBIAS)
unnamed: R29.2, U14.8 (RXD0/MODE0)
unnamed: R30.2, U14.7 (RXD1/MODE1)
unnamed: R31.2, U14.10 (RXER/PHYAD0)
unnamed: C33.1, C35.1, U14.6 (VDDCR)
unnamed: R34.2, U14.14 (~INT/REFCLKO)
P2_QSPI_SCLK: U13.52 (QSPI_SCLK); also elsewhere on the board
P2_QSPI_SD0: U13.53 (QSPI_SD0); also elsewhere on the board
P2_QSPI_SD1: U13.55 (QSPI_SD1); also elsewhere on the board
P2_QSPI_SD2: U13.54 (QSPI_SD2); also elsewhere on the board
P2_QSPI_SD3: U13.51 (QSPI_SD3); also elsewhere on the board
P2_QSPI_SS: U13.56 (QSPI_SS); also elsewhere on the board
P2_SWCLK: U13.24 (SWCLK); also elsewhere on the board
P2_SWDIO: U13.25 (SWD); also elsewhere on the board
P2_Status: R27.1, U13.2 (GPIO0)
P2_USB_DN: U13.46 (USB_DM); also elsewhere on the board
P2_USB_DP: U13.47 (USB_DP); also elsewhere on the board
eth_CRS: R32.1, U13.36 (GPIO24)
eth_MDC: U13.31 (GPIO20), U14.13 (MDC)
eth_MDIO: R33.2, U13.30 (GPIO19), U14.12 (MDIO)
eth_RETCLK: R34.1, U13.32 (GPIO21), U14.5 (XTAL1/CLKIN)
eth_RX0: R29.1, U13.34 (GPIO22)
eth_RX1: R30.1, U13.35 (GPIO23)
eth_TX0: U13.27 (GPIO16), U14.17 (TXD0)
eth_TX1: U13.28 (GPIO17), U14.18 (TXD1)
eth_TXEN: U13.29 (GPIO18), U14.16 (TXEN)

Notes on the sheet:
near p42
near p5
near p44
near p22
near LAN8720 VDD
near p1
near p49
near p45
near p23
near p33
RP2040 + Ethernet

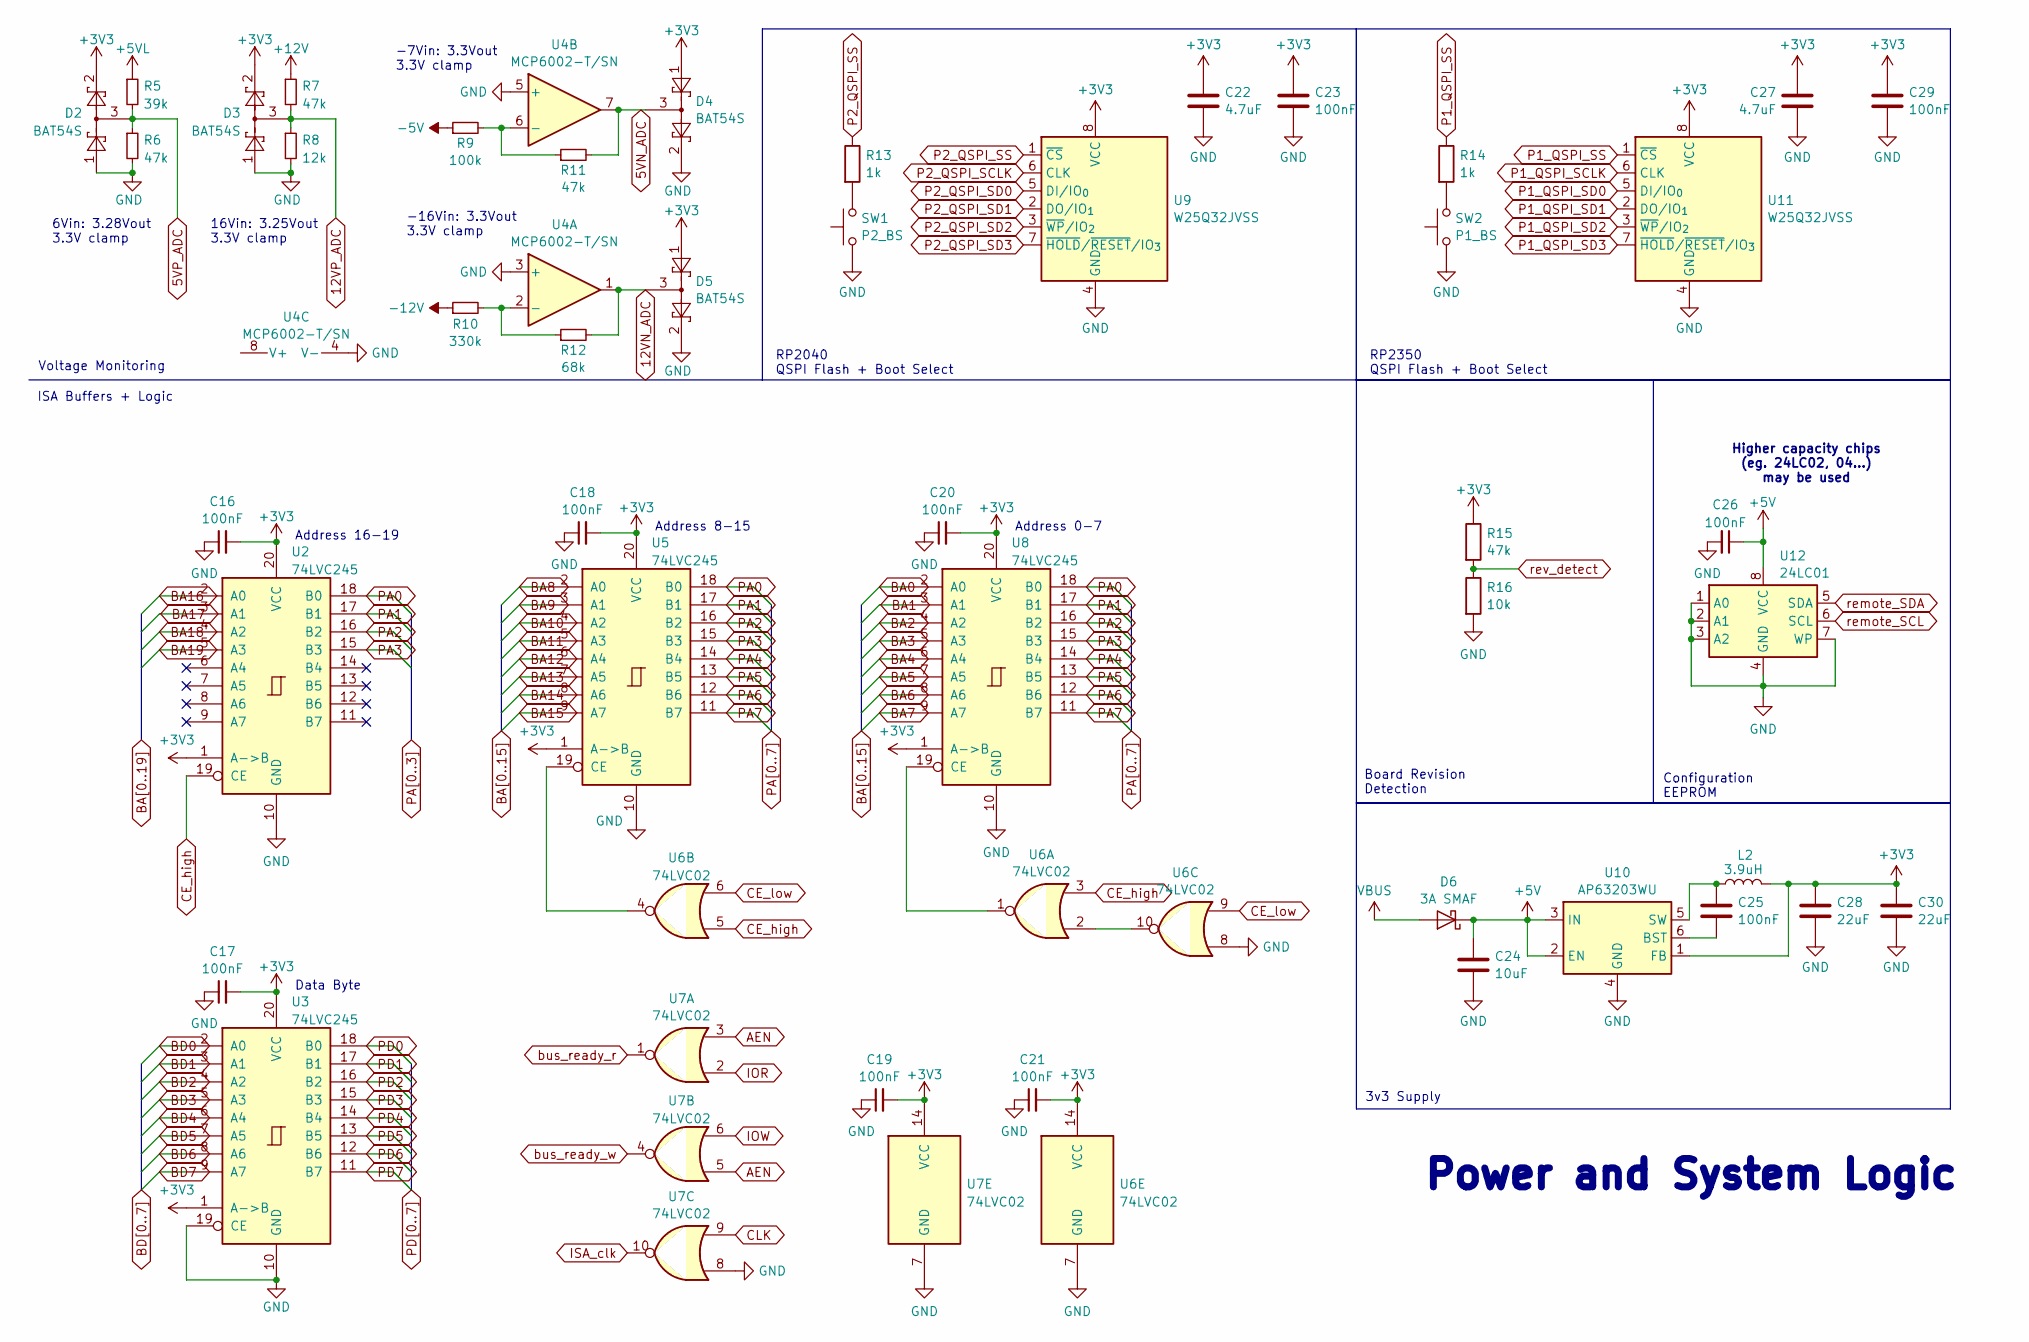
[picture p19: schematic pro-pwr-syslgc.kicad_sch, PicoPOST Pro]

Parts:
C16, C17, C18, C19, C20, C21, C23, C25, C26, C29: 100nF; C_0402_1005Metric
C22, C27: 4.7uF; C_0603_1608Metric
C24: 10uF; C_0805_2012Metric
C28, C30: 22uF; C_1206_3216Metric
D2, D3, D4, D5: BAT54S; SOT-23_Handsoldering
D6: 3A SMAF; D_SMA
L2: 3.9uH; L_APV_ANR4030
R5: 39k; R_0603_1608Metric
R6, R7, R11, R15: 47k; R_0603_1608Metric
R8: 12k; R_0603_1608Metric
R9: 100k; R_0603_1608Metric
R10: 330k; R_0603_1608Metric
R12: 68k; R_0603_1608Metric
R13, R14: 1k; R_0603_1608Metric
R16: 10k; R_0603_1608Metric
SW1: P2_BS; SW_SPST_TS-1088-xR020
SW2: P1_BS; SW_SPST_TS-1088-xR020
U2, U3, U5, U8: 74LVC245; TSSOP-20_4.4x6.5mm_P0.65mm
U4: MCP6002-T/SN; SOIC-8_3.9x4.9mm_P1.27mm
U6, U7: 74LVC02; TSSOP-14_4.4x5mm_P0.65mm
U9, U11: W25Q32JVSS; SOIC-8_5.3x5.3mm_P1.27mm
U10: AP63203WU; TSOT-23-6
U12: 24LC01; SOIC-8_3.9x4.9mm_P1.27mm

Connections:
5VN_ADC: D4.3, R11.2, U4.7; also elsewhere on the board
5VP_ADC: D2.3, R5.2, R6.1; also elsewhere on the board
12VN_ADC: D5.3, R12.2, U4.1; also elsewhere on the board
12VP_ADC: D3.3, R7.2, R8.1; also elsewhere on the board
+3V3: C16.2, C17.2, C18.2, C19.2, C20.2, C21.2, C22.1, C23.1, C27.1, C28.1, C29.1, C30.1, D2.2, D3.2, D4.1, D5.1, L2.2, R15.1, U2.1 (A->B), U2.20 (VCC), U3.1 (A->B), U3.20 (VCC), U5.1 (A->B), U5.20 (VCC), U6.14 (VCC), U7.14 (VCC), U8.1 (A->B), U8.20 (VCC), U9.8 (VCC), U10.1 (FB), U11.8 (VCC); also elsewhere on the board
+5V: C24.1, C26.1, D6.1 (K), U10.2 (EN), U10.3 (IN), U12.8 (VCC); also elsewhere on the board
+5VL: R5.1; also elsewhere on the board
+12V: R7.1; also elsewhere on the board
-5V: R9.1; also elsewhere on the board
-12V: R10.1; also elsewhere on the board
AEN: U7.3, U7.5; also elsewhere on the board
BA0: U8.2 (A0); also elsewhere on the board
BA1: U8.3 (A1); also elsewhere on the board
BA2: U8.4 (A2); also elsewhere on the board
BA3: U8.5 (A3); also elsewhere on the board
BA4: U8.6 (A4); also elsewhere on the board
BA5: U8.7 (A5); also elsewhere on the board
BA6: U8.8 (A6); also elsewhere on the board
BA7: U8.9 (A7); also elsewhere on the board
BA8: U5.2 (A0); also elsewhere on the board
BA9: U5.3 (A1); also elsewhere on the board
BA10: U5.4 (A2); also elsewhere on the board
BA11: U5.5 (A3); also elsewhere on the board
BA12: U5.6 (A4); also elsewhere on the board
BA13: U5.7 (A5); also elsewhere on the board
BA14: U5.8 (A6); also elsewhere on the board
BA15: U5.9 (A7); also elsewhere on the board
BA16: U2.2 (A0); also elsewhere on the board
BA17: U2.3 (A1); also elsewhere on the board
BA18: U2.4 (A2); also elsewhere on the board
BA19: U2.5 (A3); also elsewhere on the board
BD0: U3.2 (A0); also elsewhere on the board
BD1: U3.3 (A1); also elsewhere on the board
BD2: U3.4 (A2); also elsewhere on the board
BD3: U3.5 (A3); also elsewhere on the board
BD4: U3.6 (A4); also elsewhere on the board
BD5: U3.7 (A5); also elsewhere on the board
BD6: U3.8 (A6); also elsewhere on the board
BD7: U3.9 (A7); also elsewhere on the board
CE_high: U2.19 (CE), U6.3, U6.5; also elsewhere on the board
CE_low: U6.6, U6.9; also elsewhere on the board
CLK: U7.9; also elsewhere on the board
GND: C16.1, C17.1, C18.1, C19.1, C20.1, C21.1, C22.2, C23.2, C24.2, C26.2, C27.2, C28.2, C29.2, C30.2, D2.1, D3.1, D4.2, D5.2, R6.2, R8.2, R16.2, SW1.1, SW2.1, U2.10 (GND), U3.10 (GND), U3.19 (CE), U4.3 (+), U4.4 (V-), U4.5 (+), U5.10 (GND), U6.7 (GND), U6.8, U7.7 (GND), U7.8, U8.10 (GND), U9.4 (GND), U10.4 (GND), U11.4 (GND), U12.1 (A0), U12.2 (A1), U12.3 (A2), U12.4 (GND), U12.7 (WP); also elsewhere on the board
IOR: U7.2; also elsewhere on the board
IOW: U7.6; also elsewhere on the board
ISA_clk: U7.10; also elsewhere on the board
unnamed: R13.2, SW1.2
unnamed: R14.2, SW2.2
unnamed: R10.2, R12.1, U4.2 (-)
unnamed: R9.2, R11.1, U4.6 (-)
unnamed: U5.19 (CE), U6.4
unnamed: U6.2, U6.10
unnamed: U6.1, U8.19 (CE)
unnamed: C25.2, U10.6 (BST)
unnamed: C25.1, L2.1, U10.5 (SW)
P1_QSPI_SCLK: U11.6 (CLK); also elsewhere on the board
P1_QSPI_SD0: U11.5 (DI/IO_{0}); also elsewhere on the board
P1_QSPI_SD1: U11.2 (DO/IO_{1}); also elsewhere on the board
P1_QSPI_SD2: U11.3 (~WP/IO_{2}); also elsewhere on the board
P1_QSPI_SD3: U11.7 (~HOLD/~RESET/IO_{3}); also elsewhere on the board
P1_QSPI_SS: R14.1, U11.1 (~CS); also elsewhere on the board
P2_QSPI_SCLK: U9.6 (CLK); also elsewhere on the board
P2_QSPI_SD0: U9.5 (DI/IO_{0}); also elsewhere on the board
P2_QSPI_SD1: U9.2 (DO/IO_{1}); also elsewhere on the board
P2_QSPI_SD2: U9.3 (~WP/IO_{2}); also elsewhere on the board
P2_QSPI_SD3: U9.7 (~HOLD/~RESET/IO_{3}); also elsewhere on the board
P2_QSPI_SS: R13.1, U9.1 (~CS); also elsewhere on the board
PA0: U2.18 (B0), U5.18 (B0), U8.18 (B0); also elsewhere on the board
PA1: U2.17 (B1), U5.17 (B1), U8.17 (B1); also elsewhere on the board
PA2: U2.16 (B2), U5.16 (B2), U8.16 (B2); also elsewhere on the board
PA3: U2.15 (B3), U5.15 (B3), U8.15 (B3); also elsewhere on the board
PA4: U5.14 (B4), U8.14 (B4); also elsewhere on the board
PA5: U5.13 (B5), U8.13 (B5); also elsewhere on the board
PA6: U5.12 (B6), U8.12 (B6); also elsewhere on the board
PA7: U5.11 (B7), U8.11 (B7); also elsewhere on the board
PD0: U3.18 (B0); also elsewhere on the board
PD1: U3.17 (B1); also elsewhere on the board
PD2: U3.16 (B2); also elsewhere on the board
PD3: U3.15 (B3); also elsewhere on the board
PD4: U3.14 (B4); also elsewhere on the board
PD5: U3.13 (B5); also elsewhere on the board
PD6: U3.12 (B6); also elsewhere on the board
PD7: U3.11 (B7); also elsewhere on the board
VBUS: D6.2 (A); also elsewhere on the board
bus_ready_r: U7.1; also elsewhere on the board
bus_ready_w: U7.4; also elsewhere on the board
remote_SCL: U12.6 (SCL); also elsewhere on the board
remote_SDA: U12.5 (SDA); also elsewhere on the board
rev_detect: R15.2, R16.1; also elsewhere on the board

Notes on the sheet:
RP2350 QSPI Flash + Boot Select
Higher capacity chips (eg. 24LC02, 04...) may be used
Voltage Monitoring
Address 0-7
ISA Buffers + Logic
Data Byte
-16Vin: 3.3Vout 3.3V clamp
Address 16-19
Power and System Logic
3v3 Supply
Board Revision Detection
Address 8-15
-7Vin: 3.3Vout 3.3V clamp
Configuration EEPROM
RP2040 QSPI Flash + Boot Select
16Vin: 3.25Vout 3.3V clamp
6Vin: 3.28Vout 3.3V clamp

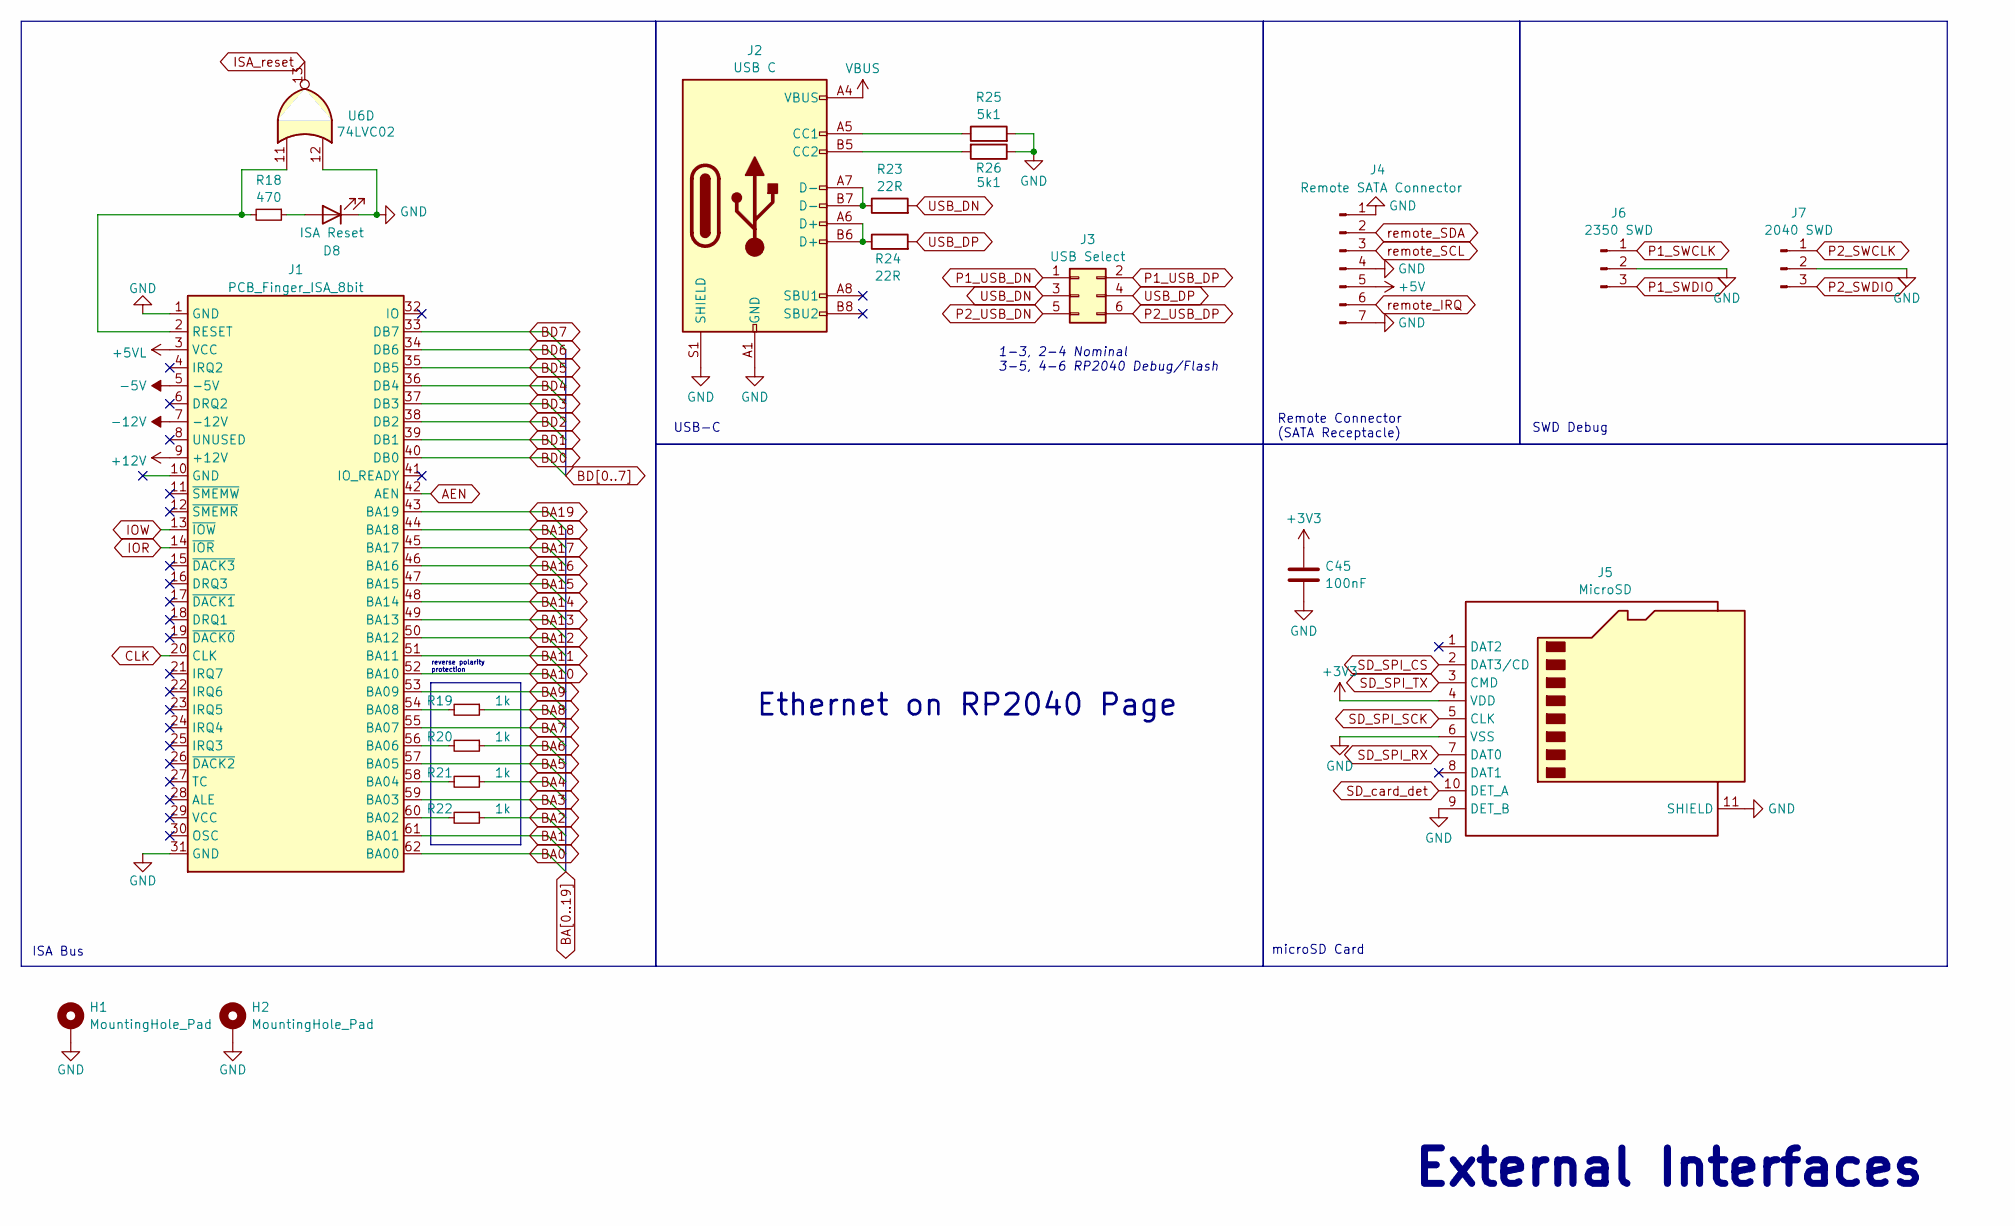
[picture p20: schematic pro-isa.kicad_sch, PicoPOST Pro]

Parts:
C45: 100nF; C_0402_1005Metric
D8: ISA Reset; D_0805_2012Metric
H1, H2: MountingHole_Pad; MountingHole_3.2mm_M3_Pad
J1: PCB_Finger_ISA_8bit; BUS_IDE8
J2: USB C; USB_C_Receptacle_G-Switch_GT-USB-7010ASV
J3: USB Select; PinHeader_2x03_P2.54mm_Vertical
J4: Remote SATA Connector; Molex-47080-4001-0-0-0
J5: MicroSD; microSD_HC_Molex_104031-0811
J6: 2350 SWD; PinHeader_1x03_P2.54mm_Vertical
J7: 2040 SWD; PinHeader_1x03_P2.54mm_Vertical
R18: 470; R_0603_1608Metric
R19, R20, R21, R22: 1k; R_0603_1608Metric
R23, R24: 22R; R_0603_1608Metric
R25, R26: 5k1; R_0603_1608Metric
U6: 74LVC02; TSSOP-14_4.4x5mm_P0.65mm

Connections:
+3V3: C45.1, J5.4 (VDD); also elsewhere on the board
+5V: J4.5; also elsewhere on the board
+5VL: J1.3 (VCC); also elsewhere on the board
+12V: J1.9 (+12V); also elsewhere on the board
-5V: J1.5 (-5V); also elsewhere on the board
-12V: J1.7 (-12V); also elsewhere on the board
AEN: J1.42 (AEN); also elsewhere on the board
BA0: J1.62 (BA00); also elsewhere on the board
BA1: J1.61 (BA01); also elsewhere on the board
BA2: R22.1; also elsewhere on the board
BA3: J1.59 (BA03); also elsewhere on the board
BA4: R21.1; also elsewhere on the board
BA5: J1.57 (BA05); also elsewhere on the board
BA6: R20.1; also elsewhere on the board
BA7: J1.55 (BA07); also elsewhere on the board
BA8: R19.1; also elsewhere on the board
BA9: J1.53 (BA09); also elsewhere on the board
BA10: J1.52 (BA10); also elsewhere on the board
BA11: J1.51 (BA11); also elsewhere on the board
BA12: J1.50 (BA12); also elsewhere on the board
BA13: J1.49 (BA13); also elsewhere on the board
BA14: J1.48 (BA14); also elsewhere on the board
BA15: J1.47 (BA15); also elsewhere on the board
BA16: J1.46 (BA16); also elsewhere on the board
BA17: J1.45 (BA17); also elsewhere on the board
BA18: J1.44 (BA18); also elsewhere on the board
BA19: J1.43 (BA19); also elsewhere on the board
BD0: J1.40 (DB0); also elsewhere on the board
BD1: J1.39 (DB1); also elsewhere on the board
BD2: J1.38 (DB2); also elsewhere on the board
BD3: J1.37 (DB3); also elsewhere on the board
BD4: J1.36 (DB4); also elsewhere on the board
BD5: J1.35 (DB5); also elsewhere on the board
BD6: J1.34 (DB6); also elsewhere on the board
BD7: J1.33 (DB7); also elsewhere on the board
CLK: J1.20 (CLK); also elsewhere on the board
GND: C45.2, D8.1 (K), H1.1, H2.1, J1.1 (GND), J1.31 (GND), J2.A1 (GND), J2.A12 (GND), J2.B1 (GND), J2.B12 (GND), J2.S1 (SHIELD), J4.1, J4.4, J4.7, J5.6 (VSS), J5.9 (DET_B), J5.11 (SHIELD), J6.2, J7.2, R25.2, R26.1, U6.12; also elsewhere on the board
IOR: J1.14 (~IOR); also elsewhere on the board
IOW: J1.13 (~IOW); also elsewhere on the board
ISA_reset: U6.13; also elsewhere on the board
unnamed: D8.2 (A), R18.1
unnamed: J1.60 (BA02), R22.2
unnamed: J1.58 (BA04), R21.2
unnamed: J1.56 (BA06), R20.2
unnamed: J1.54 (BA08), R19.2
unnamed: J1.2 (RESET), R18.2, U6.11
unnamed: J2.A5 (CC1), R25.1
unnamed: J2.B5 (CC2), R26.2
unnamed: J2.A6 (D+), J2.B6 (D+), R24.1
unnamed: J2.A7 (D-), J2.B7 (D-), R23.1
P1_SWCLK: J6.1; also elsewhere on the board
P1_SWDIO: J6.3; also elsewhere on the board
P1_USB_DN: J3.1; also elsewhere on the board
P1_USB_DP: J3.2; also elsewhere on the board
P2_SWCLK: J7.1; also elsewhere on the board
P2_SWDIO: J7.3; also elsewhere on the board
P2_USB_DN: J3.5; also elsewhere on the board
P2_USB_DP: J3.6; also elsewhere on the board
SD_SPI_CS: J5.2 (DAT3/CD); also elsewhere on the board
SD_SPI_RX: J5.7 (DAT0); also elsewhere on the board
SD_SPI_SCK: J5.5 (CLK); also elsewhere on the board
SD_SPI_TX: J5.3 (CMD); also elsewhere on the board
SD_card_det: J5.10 (DET_A); also elsewhere on the board
USB_DN: J3.3, R23.2
USB_DP: J3.4, R24.2
VBUS: J2.A4 (VBUS), J2.A9 (VBUS), J2.B4 (VBUS), J2.B9 (VBUS); also elsewhere on the board
remote_IRQ: J4.6; also elsewhere on the board
remote_SCL: J4.3; also elsewhere on the board
remote_SDA: J4.2; also elsewhere on the board

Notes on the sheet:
microSD Card
1-3, 2-4 Nominal 3-5, 4-6 RP2040 Debug/Flash
USB-C
Remote Connector (SATA Receptacle)
ISA Bus
SWD Debug
Ethernet on RP2040 Page
reverse polarity protection
External Interfaces

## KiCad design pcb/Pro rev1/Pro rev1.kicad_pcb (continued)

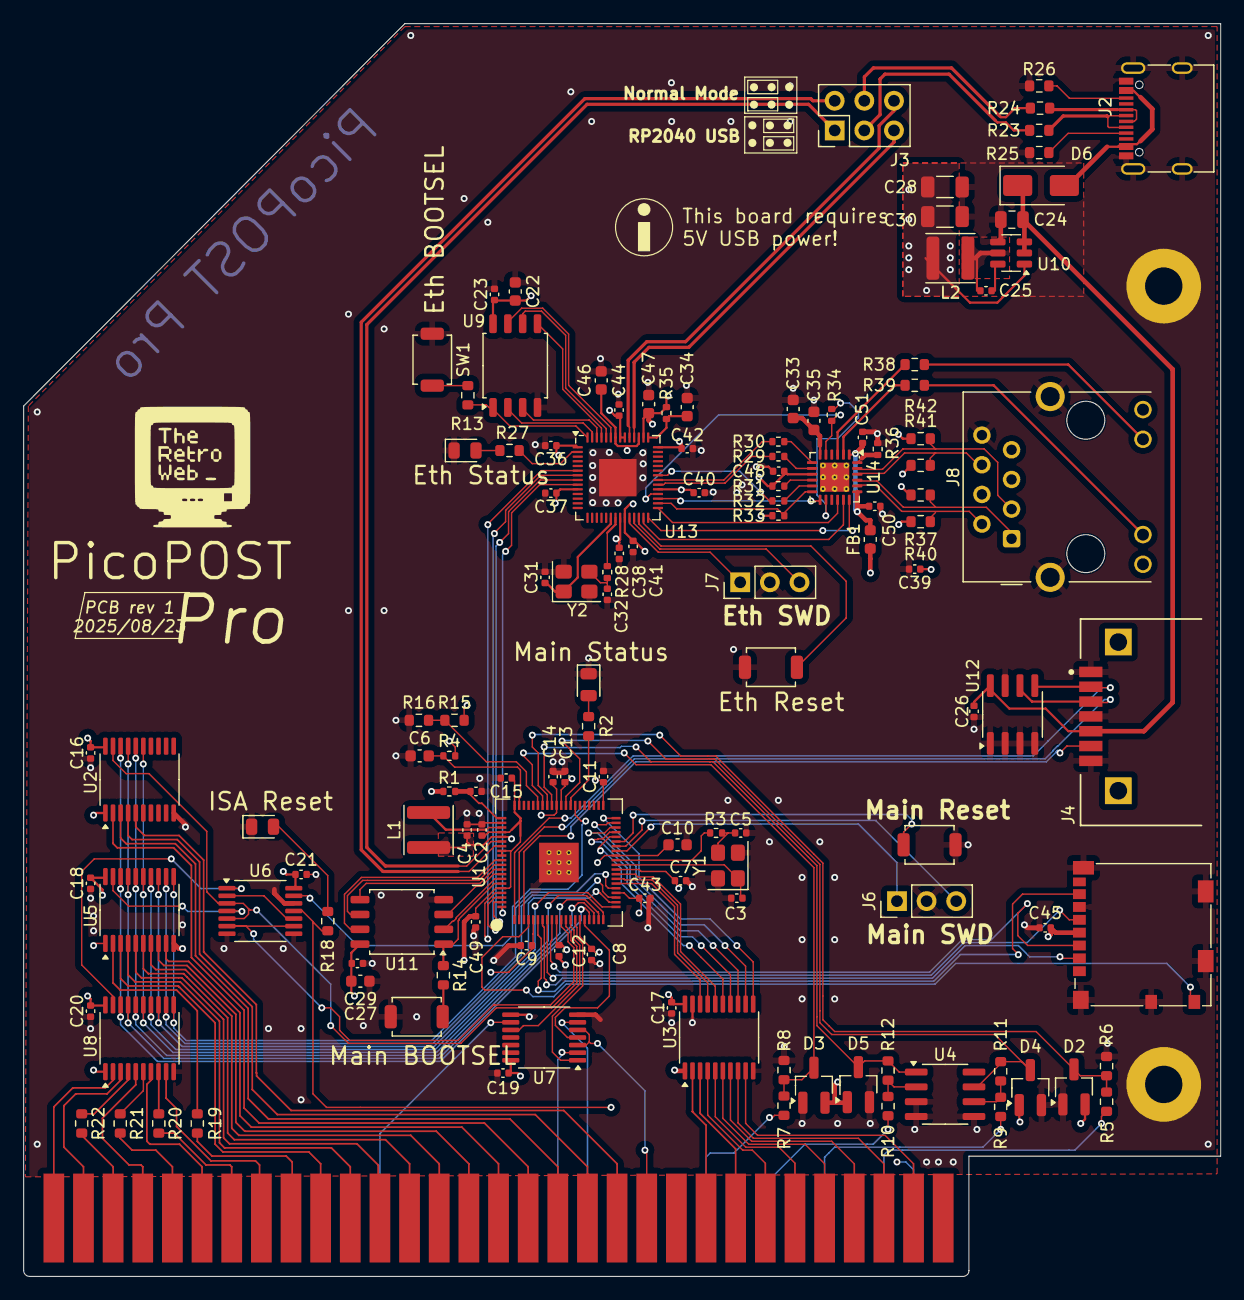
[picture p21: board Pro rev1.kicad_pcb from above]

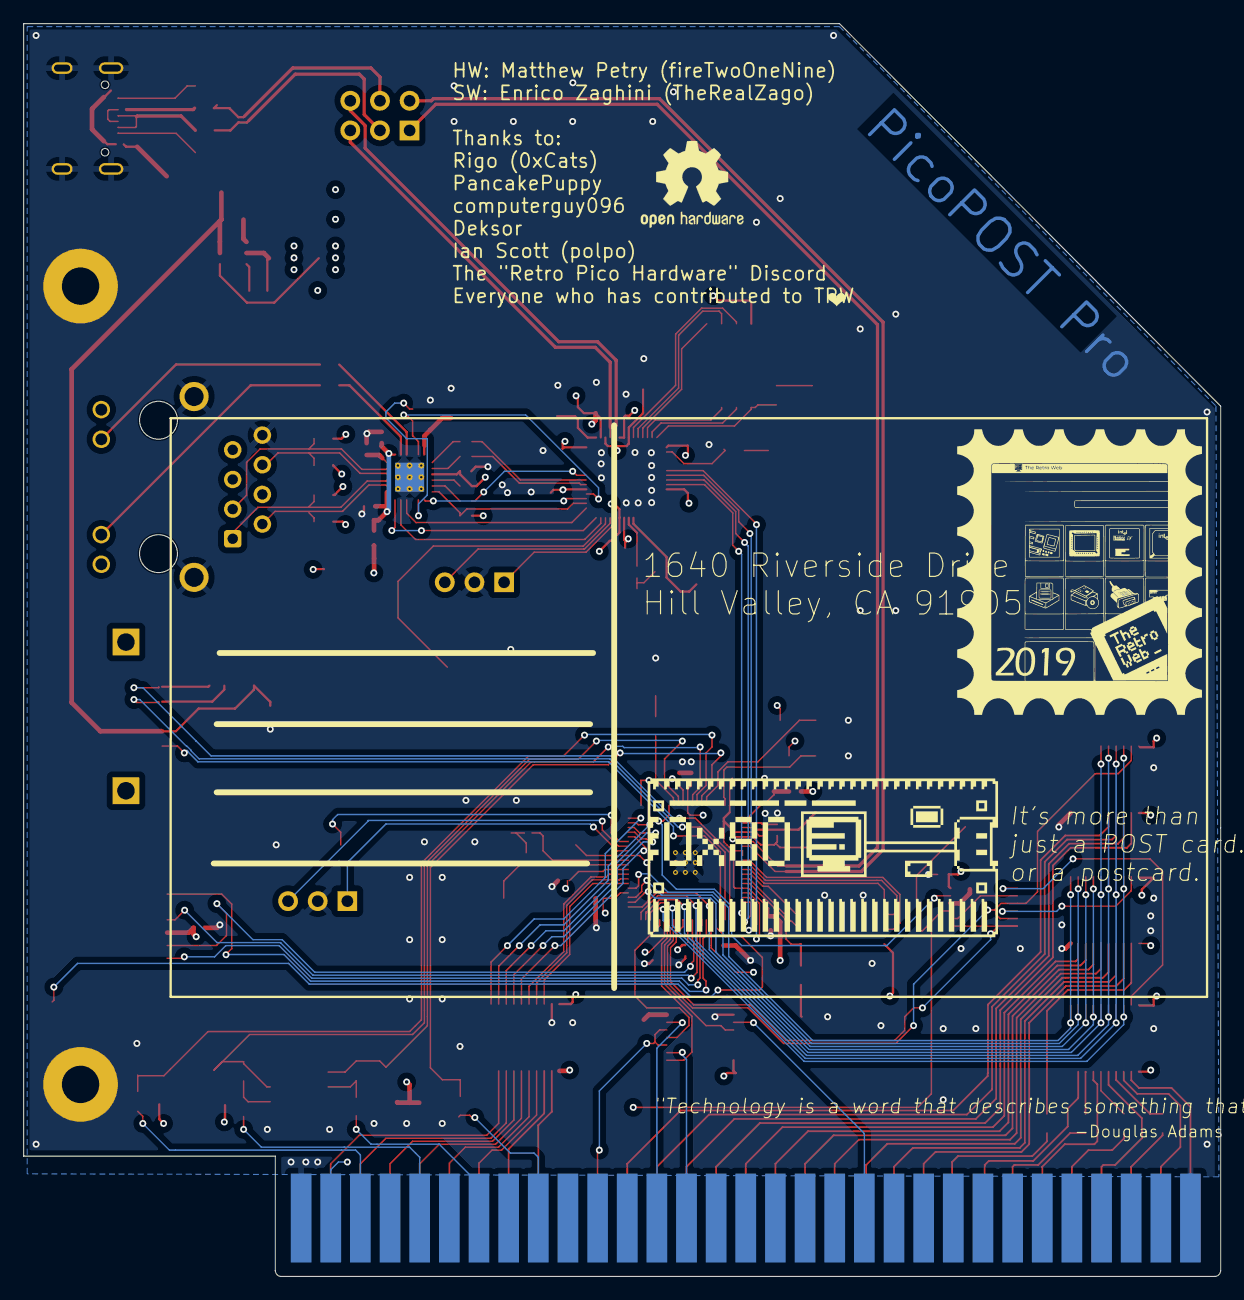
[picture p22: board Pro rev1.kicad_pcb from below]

Board: 4 copper layers, 102.6 x 107.3 mm, 136 parts (2 on the bottom side), 163 nets.

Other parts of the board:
.: LOGO; TRW_logo
.#2: LOGO; postcard_stamp
.#3: LOGO; picopost_logo

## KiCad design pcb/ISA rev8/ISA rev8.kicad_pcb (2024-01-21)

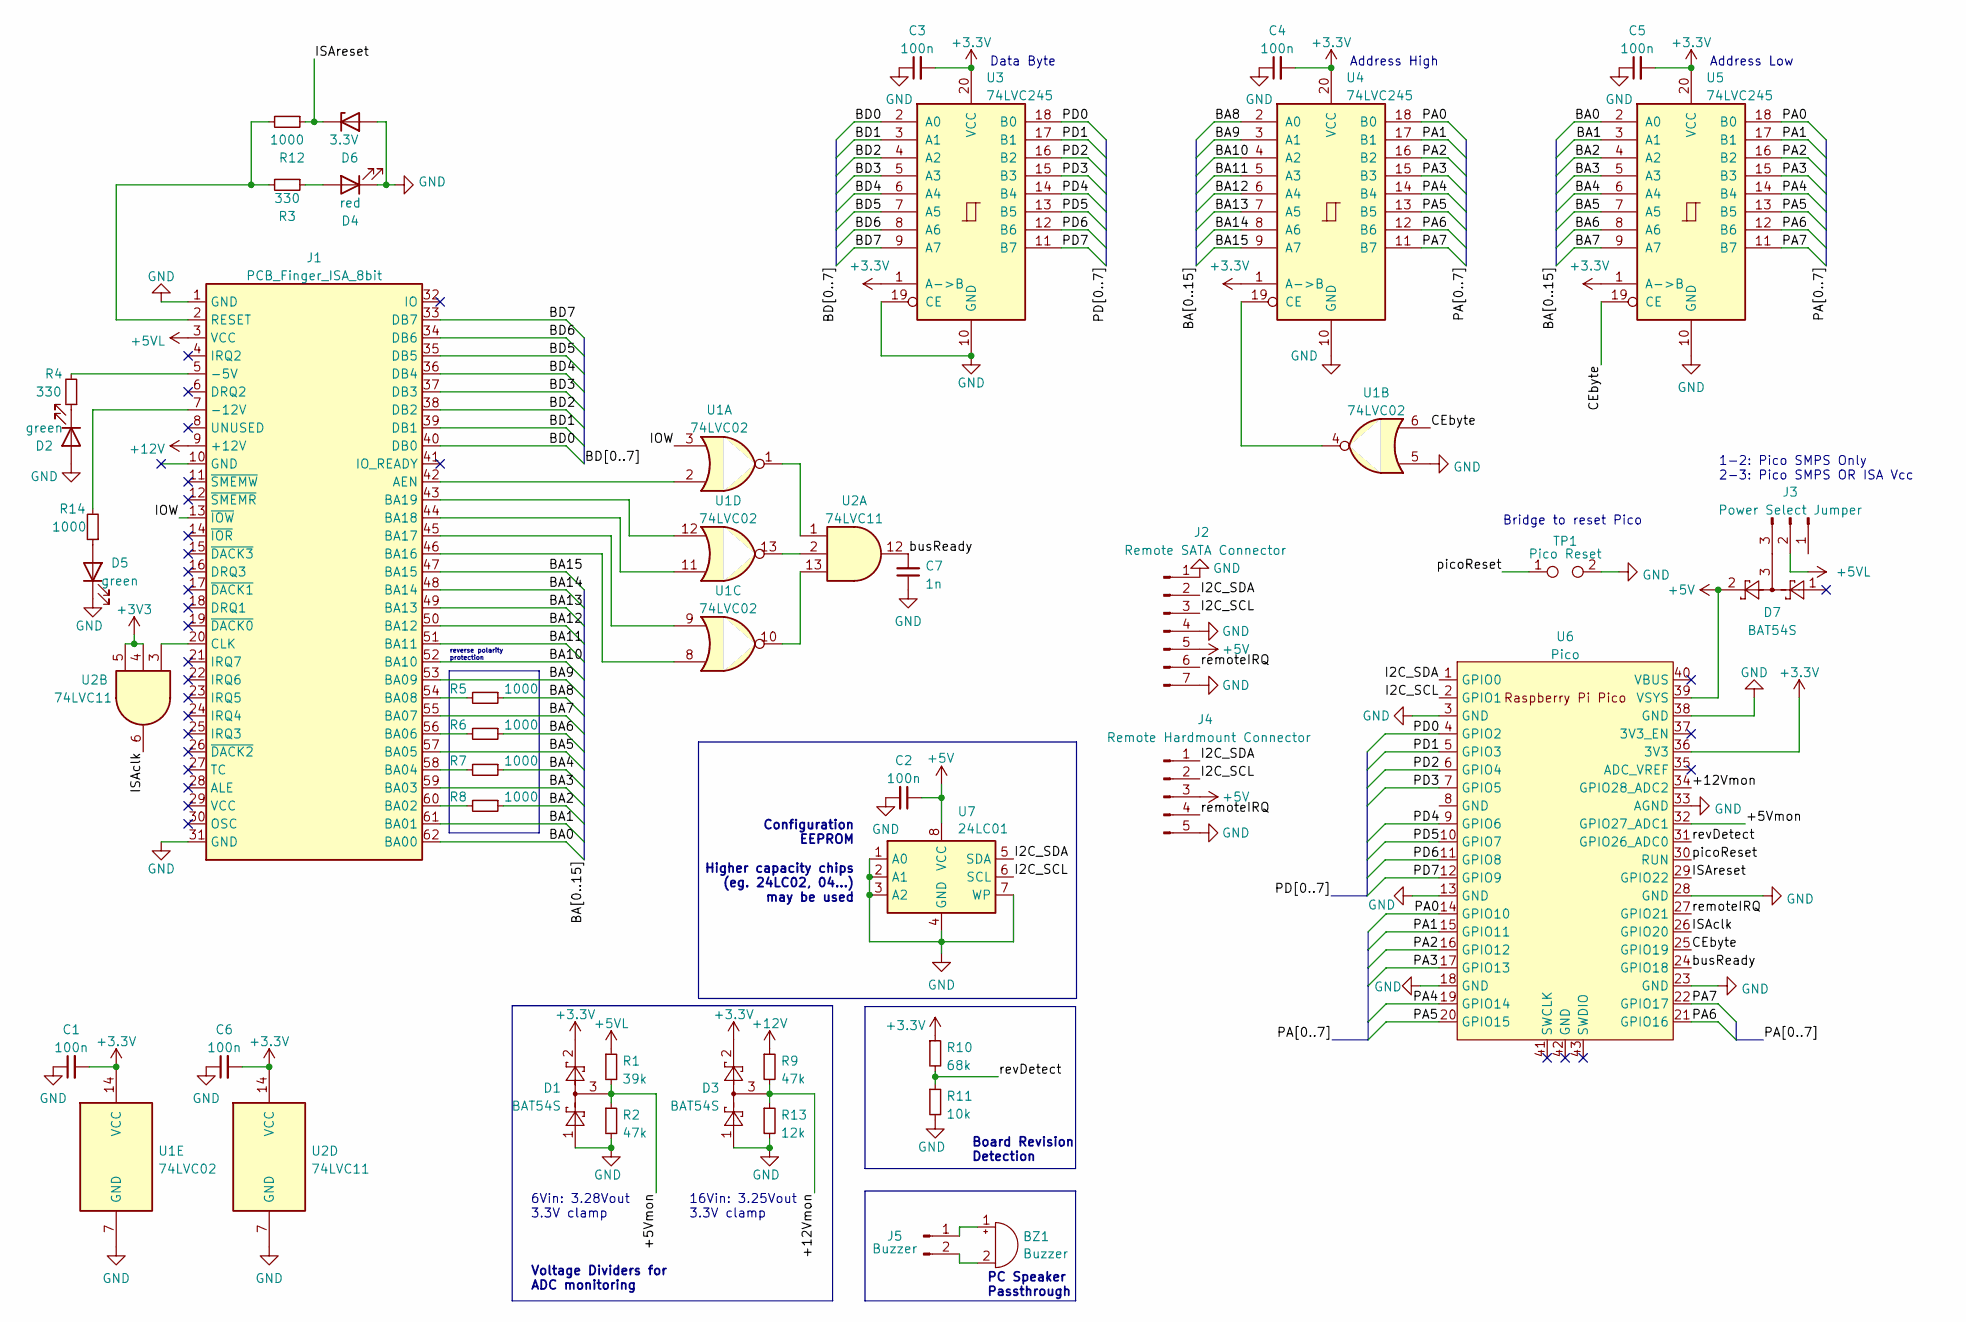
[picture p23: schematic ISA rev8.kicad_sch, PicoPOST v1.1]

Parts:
BZ1: Buzzer; 7.6mm side mount buzzer
C1, C2, C3, C4, C5, C6: 100n; C_1206_3216Metric_Pad1.33x1.80mm_HandSolder
C7: 1n; C_1206_3216Metric_Pad1.33x1.80mm_HandSolder
D1, D3, D7: BAT54S; SOT-23_Handsoldering
D2, D5: green; LED_D3.0mm
D4: red; LED_D3.0mm
D6: 3.3V; TO-236AB_diode
J1: PCB_Finger_ISA_8bit; BUS_IDE8
J2: Remote SATA Connector; Molex-47080-4001-0-0-0
J3: Power Select Jumper; PinHeader_1x03_P2.54mm_Vertical
J4: Remote Hardmount Connector; PinHeader_1x05_P2.54mm_Horizontal
J5: Buzzer; PinHeader_1x02_P2.54mm_Vertical
R1: 39k; R_1206_3216Metric_Pad1.30x1.75mm_HandSolder
R2, R9: 47k; R_1206_3216Metric_Pad1.30x1.75mm_HandSolder
R3, R4: 330; R_1206_3216Metric_Pad1.30x1.75mm_HandSolder
R5, R6, R7, R8, R12, R14: 1000; R_1206_3216Metric_Pad1.30x1.75mm_HandSolder
R10: 68k; R_1206_3216Metric_Pad1.30x1.75mm_HandSolder
R11: 10k; R_1206_3216Metric_Pad1.30x1.75mm_HandSolder
R13: 12k; R_1206_3216Metric_Pad1.30x1.75mm_HandSolder
TP1: Pico Reset; 6mm single side button
U1: 74LVC02; SO-14_3.9x8.65mm_P1.27mm
U2: 74LVC11; SO-14_3.9x8.65mm_P1.27mm
U3, U4, U5: 74LVC245; SO-20_5.3x12.6mm_P1.27mm
U6: Pico; RPi_Pico_SMD_TH
U7: 24LC01; SOIC-8_3.9x4.9mm_P1.27mm

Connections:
+5V: C2.1, D7.2, J2.5, J4.3, U6.39 (VSYS), U7.8 (VCC)
+5VL: J1.3 (VCC), J3.2, R1.1
+12V: J1.9 (+12V), R9.1
/+5Vmon: D1.3, R1.2, R2.1, U6.32 (GPIO27_ADC1)
/+12Vmon: D3.3, R9.2, R13.1, U6.34 (GPIO28_ADC2)
/BA0: J1.62 (BA00), U5.2 (A0)
/BA1: J1.61 (BA01), U5.3 (A1)
/BA2: R8.1, U5.4 (A2)
/BA3: J1.59 (BA03), U5.5 (A3)
/BA4: R7.1, U5.6 (A4)
/BA5: J1.57 (BA05), U5.7 (A5)
/BA6: R6.1, U5.8 (A6)
/BA7: J1.55 (BA07), U5.9 (A7)
/BA8: R5.1, U4.2 (A0)
/BA9: J1.53 (BA09), U4.3 (A1)
/BA10: J1.52 (BA10), U4.4 (A2)
/BA11: J1.51 (BA11), U4.5 (A3)
/BA12: J1.50 (BA12), U4.6 (A4)
/BA13: J1.49 (BA13), U4.7 (A5)
/BA14: J1.48 (BA14), U4.8 (A6)
/BA15: J1.47 (BA15), U4.9 (A7)
/BD0: J1.40 (DB0), U3.2 (A0)
/BD1: J1.39 (DB1), U3.3 (A1)
/BD2: J1.38 (DB2), U3.4 (A2)
/BD3: J1.37 (DB3), U3.5 (A3)
/BD4: J1.36 (DB4), U3.6 (A4)
/BD5: J1.35 (DB5), U3.7 (A5)
/BD6: J1.34 (DB6), U3.8 (A6)
/BD7: J1.33 (DB7), U3.9 (A7)
/CEbyte: U1.6, U5.19 (CE), U6.25 (GPIO19)
/I2C_SCL: J2.3, J4.2, U6.2 (GPIO1), U7.6 (SCL)
/I2C_SDA: J2.2, J4.1, U6.1 (GPIO0), U7.5 (SDA)
/IOW: J1.13 (~IOW), U1.3
/ISAclk: U2.6, U6.26 (GPIO20)
/ISAreset: D6.1 (K), R12.1, U6.29 (GPIO22)
/PA0: U4.18 (B0), U5.18 (B0), U6.14 (GPIO10)
/PA1: U4.17 (B1), U5.17 (B1), U6.15 (GPIO11)
/PA2: U4.16 (B2), U5.16 (B2), U6.16 (GPIO12)
/PA3: U4.15 (B3), U5.15 (B3), U6.17 (GPIO13)
/PA4: U4.14 (B4), U5.14 (B4), U6.19 (GPIO14)
/PA5: U4.13 (B5), U5.13 (B5), U6.20 (GPIO15)
/PA6: U4.12 (B6), U5.12 (B6), U6.21 (GPIO16)
/PA7: U4.11 (B7), U5.11 (B7), U6.22 (GPIO17)
/PD0: U3.18 (B0), U6.4 (GPIO2)
/PD1: U3.17 (B1), U6.5 (GPIO3)
/PD2: U3.16 (B2), U6.6 (GPIO4)
/PD3: U3.15 (B3), U6.7 (GPIO5)
/PD4: U3.14 (B4), U6.9 (GPIO6)
/PD5: U3.13 (B5), U6.10 (GPIO7)
/PD6: U3.12 (B6), U6.11 (GPIO8)
/PD7: U3.11 (B7), U6.12 (GPIO9)
/busReady: C7.2, U2.12, U6.24 (GPIO18)
/picoReset: TP1.1, U6.30 (RUN)
/remoteIRQ: J2.6, J4.4, U6.27 (GPIO21)
/revDetect: R10.2, R11.1, U6.31 (GPIO26_ADC0)
GND: C1.1, C2.2, C3.1, C4.1, C5.1, C6.1, C7.1, D1.1, D2.2 (A), D3.1, D4.1 (K), D5.1 (K), D6.2 (A), J1.1 (GND), J1.31 (GND), J2.1, J2.4, J2.7, J4.5, R2.2, R11.2, R13.2, TP1.2, U1.5, U1.7 (GND), U2.7 (GND), U3.10 (GND), U3.19 (CE), U4.10 (GND), U5.10 (GND), U6.3 (GND), U6.13 (GND), U6.18 (GND), U6.23 (GND), U6.28 (GND), U6.33 (AGND), U6.38 (GND), U7.1 (A0), U7.2 (A1), U7.3 (A2), U7.4 (GND), U7.7 (WP)
unnamed: BZ1.2 (+), J5.2
unnamed: BZ1.1 (-), J5.1
unnamed: D2.1 (K), R4.1
unnamed: D4.2 (A), R3.1
unnamed: D5.2 (A), R14.1
unnamed: J1.5 (-5V), R4.2
unnamed: J1.7 (-12V), R14.2
unnamed: J1.42 (AEN), U1.2
unnamed: J1.60 (BA02), R8.2
unnamed: J1.58 (BA04), R7.2
unnamed: J1.56 (BA06), R6.2
unnamed: J1.54 (BA08), R5.2
unnamed: J1.46 (BA16), U1.8
unnamed: J1.45 (BA17), U1.9
unnamed: J1.44 (BA18), U1.11
unnamed: J1.43 (BA19), U1.12
unnamed: J1.20 (CLK), U2.3
unnamed: J1.2 (RESET), R3.2, R12.2
unnamed: D7.3, J3.3
unnamed: U1.1, U2.1
unnamed: U1.10, U2.13
unnamed: U1.13, U2.2
unnamed: U1.4, U4.19 (CE)

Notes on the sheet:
6Vin: 3.28Vout 3.3V clamp
Configuration EEPROM Higher capacity chips (eg. 24LC02, 04...) may be used
Board Revision Detection
Voltage Dividers for ADC monitoring
reverse polarity protection
Data Byte
Bridge to reset Pico
Address High
1-2: Pico SMPS Only 2-3: Pico SMPS OR ISA Vcc
PC Speaker Passthrough
Address Low
16Vin: 3.25Vout 3.3V clamp

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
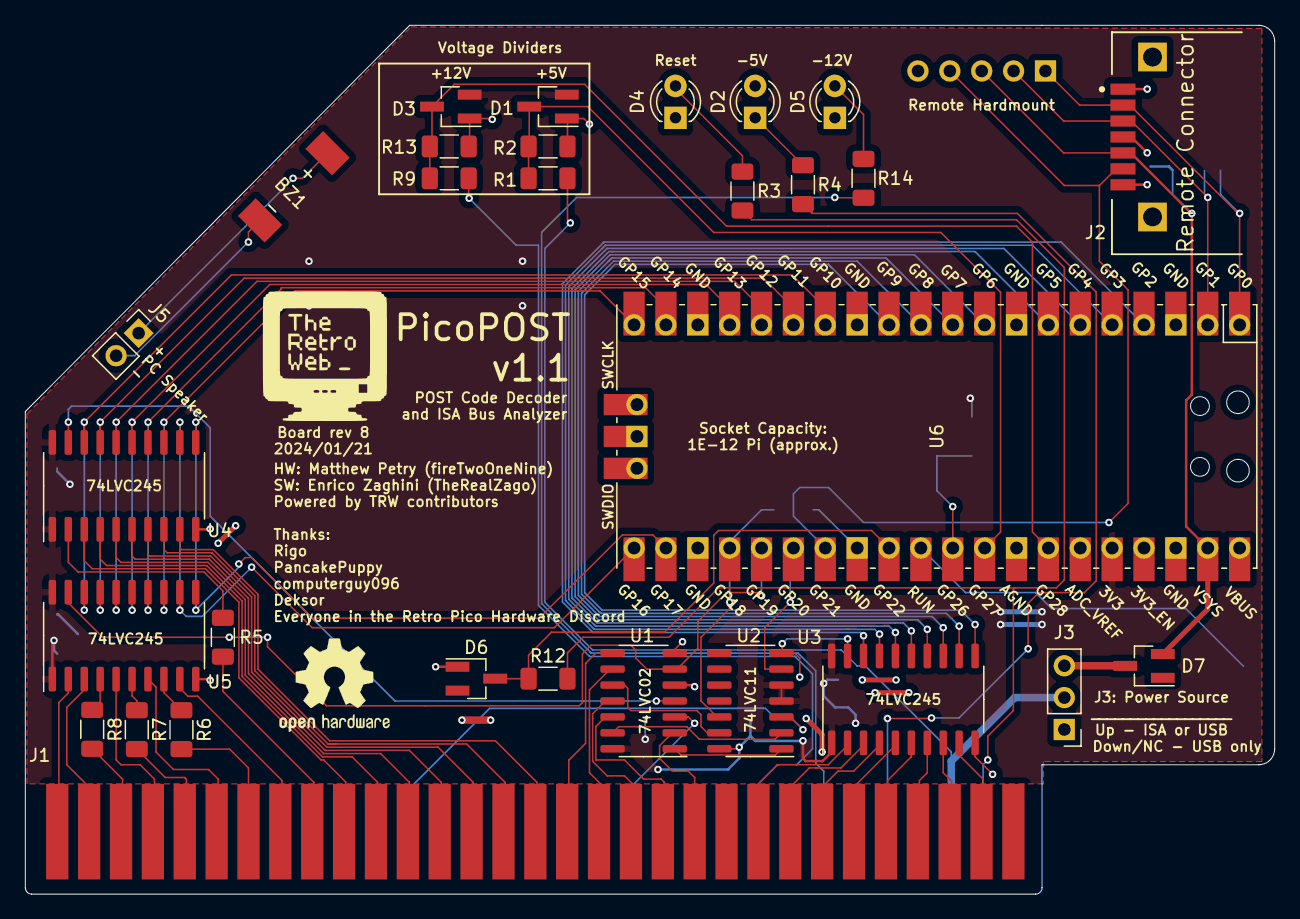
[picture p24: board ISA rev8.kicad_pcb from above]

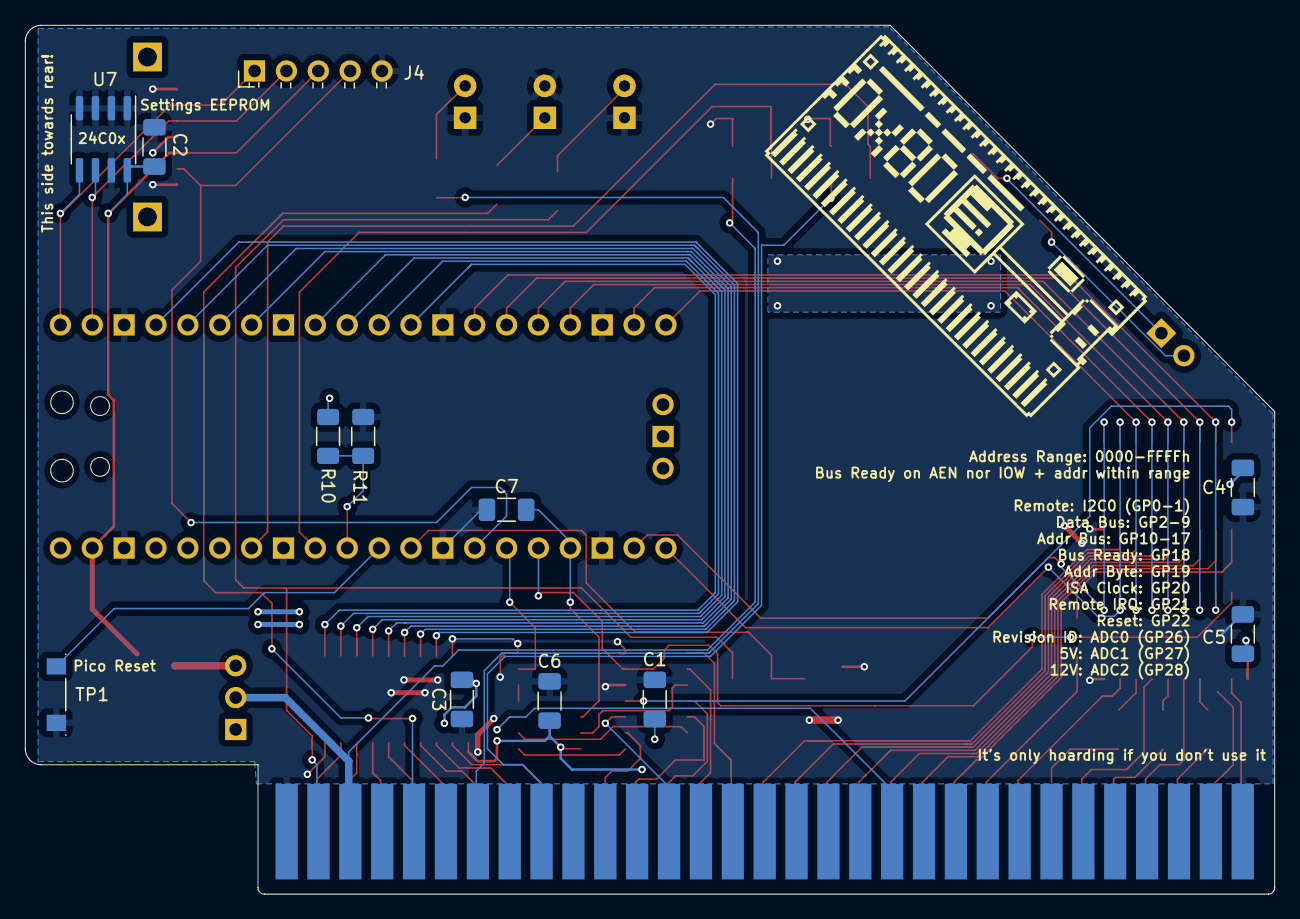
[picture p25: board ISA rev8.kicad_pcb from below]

Board: 2 copper layers, 99.6 x 69.2 mm, 43 parts (13 on the bottom side), 80 nets.

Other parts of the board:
.: LOGO; picopost_logo

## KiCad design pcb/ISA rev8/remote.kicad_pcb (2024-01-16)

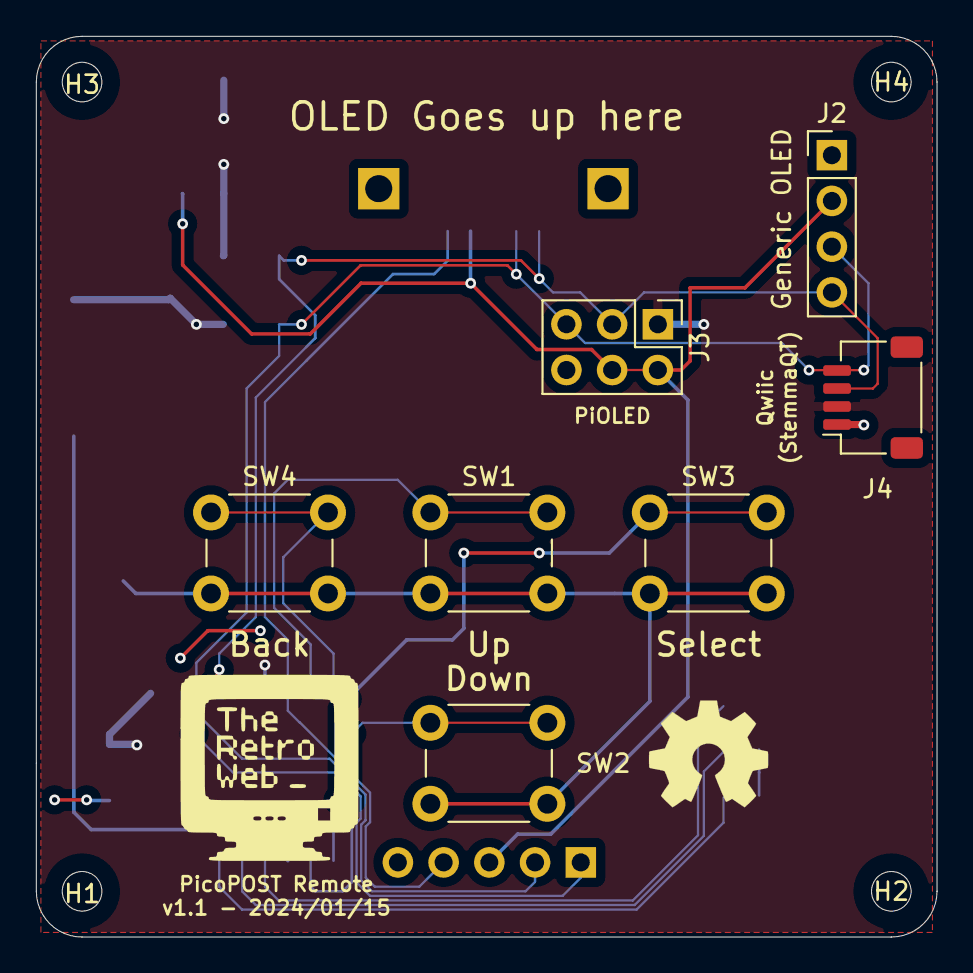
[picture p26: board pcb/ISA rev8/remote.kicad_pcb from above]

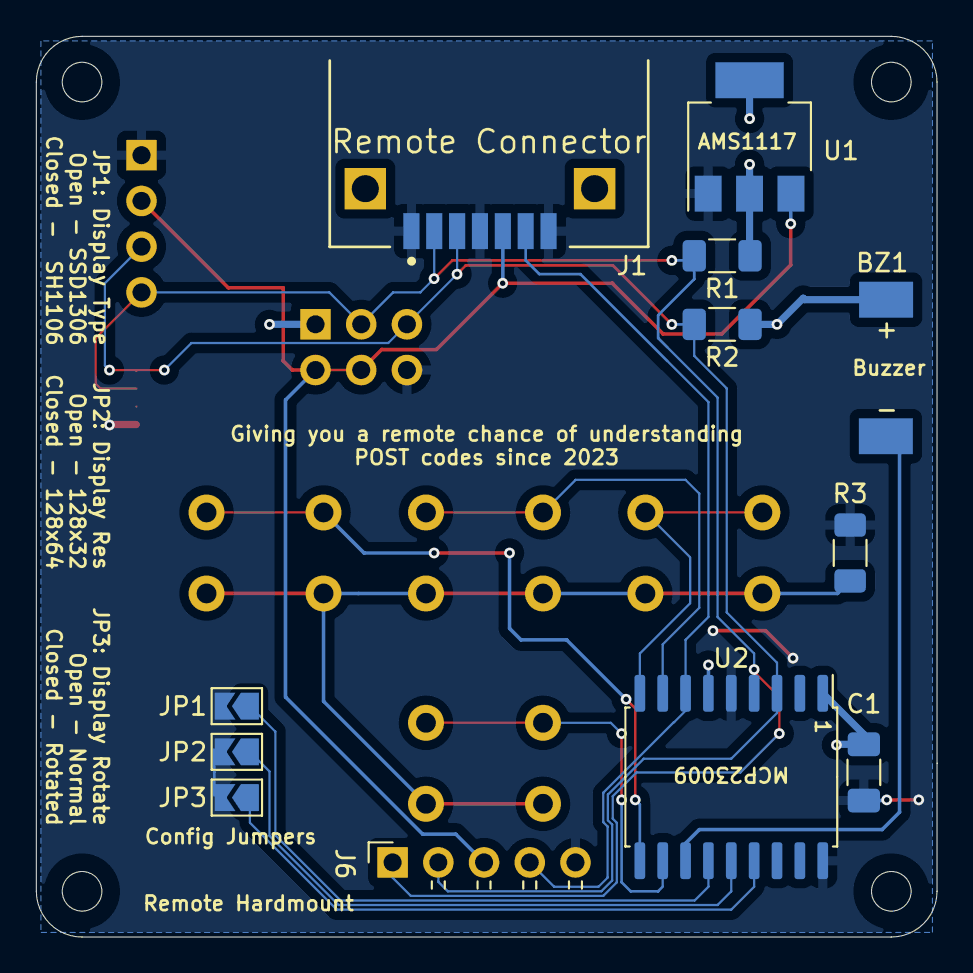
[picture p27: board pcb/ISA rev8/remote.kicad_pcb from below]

Board: 2 copper layers, 50.0 x 50.0 mm, 23 parts (12 on the bottom side), 15 nets.

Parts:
BZ1: Buzzer; 7.6mm side mount buzzer
C1: 100n; C_1206_3216Metric_Pad1.33x1.80mm_HandSolder
H1, H2, H3, H4: MountingHole; MountingHole_2.2mm_M2
J1: Remote Connector; Molex-47080-4001-0-0-0
J2: Generic Connector; PinHeader_1x04_P2.54mm_Vertical
J3: PiOLED Connector; PinHeader_2x03_P2.54mm_Vertical
J4: Qwiic/STEMMA QT; JST_SH_SM04B-SRSS-TB_1x04-1MP_P1.00mm_Horizontal
J6: Remote Hardmount Connector; PinSocket_1x05_P2.54mm_Horizontal
JP1: Display Type; SolderJumper-2_P1.3mm_Open_TrianglePad1.0x1.5mm
JP2: Display Resolution; SolderJumper-2_P1.3mm_Open_TrianglePad1.0x1.5mm
JP3: Display Rotate; SolderJumper-2_P1.3mm_Open_TrianglePad1.0x1.5mm
R1, R2, R3: 1000; R_1206_3216Metric_Pad1.30x1.75mm_HandSolder
SW1: Up; SW_PUSH_6mm
SW2: Down; SW_PUSH_6mm
SW3: Select; SW_PUSH_6mm
SW4: Back; SW_PUSH_6mm
U1: AMS1117-3.3; SOT-223-3_TabPin2
U2: MCP23009-SO; SOIC-18W_7.5x11.6mm_P1.27mm

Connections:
+3V3: BZ1.1 (-), C1.1, J3.1, J4.2, R1.1, R2.1, U1.2 (VO), U2.1 (VDD), U2.6 (~RESET)
+5V: J1.5, J2.2, J3.2, J3.4, J6.3, U1.3 (VI)
/IRQ: J1.6, J6.4, U2.7 (INT)
/SCL: J1.3, J2.3, J3.5, J4.4, J6.2, R2.2, U2.3 (SCL)
/SDA: J1.2, J2.4, J3.3, J4.3, J6.1, R1.2, U2.4 (SDA)
GND: C1.2, J1.1, J1.4, J1.7, J2.1, J3.6, J4.1, J6.5, JP1.2 (B), JP2.2 (B), JP3.2 (B), R3.1, U1.1 (GND), U2.5 (ADDR), U2.18 (VSS)
unnamed: BZ1.2 (+), U2.12 (GP4)
unnamed: JP1.1 (A), U2.13 (GP5)
unnamed: JP2.1 (A), U2.14 (GP6)
unnamed: JP3.1 (A), U2.15 (GP7)
unnamed: R3.2, SW1.2, SW2.2, SW3.2, SW4.2
unnamed: SW1.1, U2.8 (GP0)
unnamed: SW4.1, U2.9 (GP1)
unnamed: SW3.1, U2.10 (GP2)
unnamed: SW2.1, U2.11 (GP3)

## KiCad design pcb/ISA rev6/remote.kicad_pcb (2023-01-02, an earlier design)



Board: 2 copper layers, 50.0 x 50.0 mm, 20 parts (9 on the bottom side), 15 nets.

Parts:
BZ1: Buzzer; 7.6mm side mount buzzer
C1: 100n; C_1206_3216Metric_Pad1.33x1.80mm_HandSolder
H1, H2, H3, H4: MountingHole; MountingHole_2.2mm_M2
J1: Remote Connector; Molex-47080-4001-0-0-0
J2: Generic Connector; PinHeader_1x04_P2.54mm_Vertical
J3: PiOLED Connector; PinHeader_2x03_P2.54mm_Vertical
J4: Qwiic/STEMMA QT; JST_SH_SM04B-SRSS-TB_1x04-1MP_P1.00mm_Horizontal
J5: Config Jumpers; 2x03 solder jumper
R1, R2, R3: 1000; R_1206_3216Metric_Pad1.30x1.75mm_HandSolder
SW1: Up; SW_PUSH_6mm
SW2: Down; SW_PUSH_6mm
SW3: Select; SW_PUSH_6mm
SW4: Back; SW_PUSH_6mm
U1: AMS1117-3.3; SOT-223-3_TabPin2
U2: MCP23009-SO; SOIC-18W_7.5x11.6mm_P1.27mm

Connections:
+3V3: BZ1.1 (-), C1.1, J3.1, J4.2, J5.2, J5.4, J5.6, R1.1, R2.1, U1.2 (VO), U2.1 (VDD)
+5V: J1.3, J2.2, J3.2, J3.4, U1.3 (VI)
/IRQ: J1.2, U2.7 (INT)
/SCL: J1.5, J2.3, J3.5, J4.4, R2.2, U2.3 (SCL)
/SDA: J1.6, J2.4, J3.3, J4.3, R1.2, U2.4 (SDA)
GND: C1.2, J1.1, J1.4, J1.7, J2.1, J3.6, J4.1, R3.1, U1.1 (GND), U2.5 (ADDR), U2.6 (~RESET), U2.18 (VSS)
unnamed: BZ1.2 (+), U2.12 (GP4)
unnamed: R3.2, SW1.2, SW2.2, SW3.2, SW4.2
unnamed: SW1.1, U2.8 (GP0)
unnamed: SW2.1, U2.9 (GP1)
unnamed: SW3.1, U2.10 (GP2)
unnamed: SW4.1, U2.11 (GP3)
unnamed: J5.1, U2.13 (GP5)
unnamed: J5.3, U2.14 (GP6)
unnamed: J5.5, U2.15 (GP7)

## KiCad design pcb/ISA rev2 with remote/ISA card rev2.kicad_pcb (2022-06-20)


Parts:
D1: green; LED_D3.0mm
D4: red; LED_D3.0mm
J1: PCB_Finger_ISA_8bit; BUS_IDE8
J2: OLED Header; PinHeader_1x05_P2.54mm_Vertical
J3: remote header; PinSocket_1x08_P2.54mm_Vertical
J4: OLED here; PinSocket_1x05_P2.54mm_Vertical
J5: Button Header; PinHeader_1x03_P2.54mm_Vertical
R1, R5, R6, R7, R8, R13: 1000; R_1206_3216Metric_Pad1.30x1.75mm_HandSolder
R2: 33k; R_1206_3216Metric_Pad1.30x1.75mm_HandSolder
R3: 330; R_1206_3216Metric_Pad1.30x1.75mm_HandSolder
R4: 68k; R_1206_3216Metric_Pad1.30x1.75mm_HandSolder
R9: 12k; R_1206_3216Metric_Pad1.30x1.75mm_HandSolder
R10: 56k; R_1206_3216Metric_Pad1.30x1.75mm_HandSolder
R11: 47k; R_1206_3216Metric_Pad1.30x1.75mm_HandSolder
R12: 18k; R_1206_3216Metric_Pad1.30x1.75mm_HandSolder
SW1: Up; SW_PUSH_6mm_H5mm
SW2: Down; SW_PUSH_6mm_H5mm
SW3: Select/Menu; SW_PUSH_6mm_H5mm
U1: 74LVC02; SO-14_3.9x8.65mm_P1.27mm
U2, U3, U4: 74LVC245; SO-20_5.3x12.6mm_P1.27mm
U5: Pico; RPi_Pico_SMD_TH

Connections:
+3V3: J2.2, U1.14 (VCC), U2.1 (A->B), U2.20 (VCC), U3.1 (A->B), U3.20 (VCC), U4.1 (A->B), U4.20 (VCC), U5.36 (3V3)
+5V: J1.3 (VCC), J2.1, R2.1, R3.1, R10.2, U5.39 (VSYS)
/+5Vmon: R2.2, R4.1, U5.31 (GPIO26_ADC0)
/+12Vmon: R11.2, R12.1, U5.34 (GPIO28_ADC2)
/-5Vmon: R9.2, R10.1, U5.32 (GPIO27_ADC1)
/BA0: J1.62 (BA00), U4.2 (A0)
/BA1: J1.61 (BA01), U4.3 (A1)
/BA2: R8.1, U4.4 (A2)
/BA3: J1.59 (BA03), U4.5 (A3)
/BA4: R7.1, U4.6 (A4)
/BA5: J1.57 (BA05), U4.7 (A5)
/BA6: R6.1, U4.8 (A6)
/BA7: J1.55 (BA07), U4.9 (A7)
/BA8: R5.1, U3.2 (A0)
/BA9: J1.53 (BA09), U3.3 (A1)
/BA10: J1.52 (BA10), U3.4 (A2)
/BA11: J1.51 (BA11), U3.5 (A3)
/BA12: J1.50 (BA12), U3.6 (A4)
/BA13: J1.49 (BA13), U3.7 (A5)
/BA14: J1.48 (BA14), U3.8 (A6)
/BA15: J1.47 (BA15), U3.9 (A7)
/BD0: J1.40 (DB0), U2.2 (A0)
/BD1: J1.39 (DB1), U2.3 (A1)
/BD2: J1.38 (DB2), U2.4 (A2)
/BD3: J1.37 (DB3), U2.5 (A3)
/BD4: J1.36 (DB4), U2.6 (A4)
/BD5: J1.35 (DB5), U2.7 (A5)
/BD6: J1.34 (DB6), U2.8 (A6)
/BD7: J1.33 (DB7), U2.9 (A7)
/OLED_SCL: J2.5, U5.2 (GPIO1)
/OLED_SDA: J2.4, U5.1 (GPIO0)
/PA0: U3.18 (B0), U4.18 (B0), U5.14 (GPIO10)
/PA1: U3.17 (B1), U4.17 (B1), U5.15 (GPIO11)
/PA2: U3.16 (B2), U4.16 (B2), U5.16 (GPIO12)
/PA3: U3.15 (B3), U4.15 (B3), U5.17 (GPIO13)
/PA4: U3.14 (B4), U4.14 (B4), U5.19 (GPIO14)
/PA5: U3.13 (B5), U4.13 (B5), U5.20 (GPIO15)
/PA6: U3.12 (B6), U4.12 (B6), U5.21 (GPIO16)
/PA7: U3.11 (B7), U4.11 (B7), U5.22 (GPIO17)
/PD0: U2.18 (B0), U5.4 (GPIO2)
/PD1: U2.17 (B1), U5.5 (GPIO3)
/PD2: U2.16 (B2), U5.6 (GPIO4)
/PD3: U2.15 (B3), U5.7 (GPIO5)
/PD4: U2.14 (B4), U5.9 (GPIO6)
/PD5: U2.13 (B5), U5.10 (GPIO7)
/PD6: U2.12 (B6), U5.11 (GPIO8)
/PD7: U2.11 (B7), U5.12 (GPIO9)
/addr_byte: U1.6, U4.19 (CE), U5.25 (GPIO19)
/bus_ready: U1.1, U5.24 (GPIO18)
/remote_GND: J3.6, J4.3, R13.2
GND: D1.1 (K), J1.1 (GND), J1.10 (GND), J1.31 (GND), J2.3, R4.2, R12.2, U1.5, U1.7 (GND), U2.10 (GND), U2.19 (CE), U3.10 (GND), U4.10 (GND), U5.3 (GND), U5.18 (GND), U5.28 (GND), U5.33 (AGND), U5.38 (GND)
unnamed: D1.2 (A), R1.1
unnamed: D4.1 (K), R3.2
unnamed: D4.2 (A), J1.2 (RESET)
unnamed: J1.5 (-5V), R9.1
unnamed: J1.7 (-12V), R1.2
unnamed: J1.9 (+12V), R11.1
unnamed: J1.13 (~IOW), U1.2
unnamed: J1.42 (AEN), U1.3
unnamed: J1.54 (BA08), R5.2
unnamed: J1.56 (BA06), R6.2
unnamed: J1.58 (BA04), R7.2
unnamed: J1.60 (BA02), R8.2
unnamed: J3.4, J4.5
unnamed: J3.5, J4.4
unnamed: J3.7, J4.2
unnamed: J3.8, J4.1
unnamed: R13.1, SW1.1, SW2.1, SW3.1
unnamed: J3.1, SW1.2
unnamed: J3.2, SW2.2
unnamed: J3.3, SW3.2
unnamed: U1.4, U3.19 (CE)
unnamed: J5.1, U5.26 (GPIO20)
unnamed: J5.2, U5.27 (GPIO21)
unnamed: J5.3, U5.29 (GPIO22)

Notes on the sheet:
up down select 5V 3.3V GND SDA SCL
reverse polarity protection
remote control
select down up
Data Byte
Address High
Address Low
5V 3.3V GND SDA SCL
voltage dividers for ADC monitoring


Board: 2 copper layers, 81.3 x 87.6 mm, 28 parts (0 on the bottom side), 75 nets.

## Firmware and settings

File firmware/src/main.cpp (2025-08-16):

/**
 *    src/main.c
 *
 *    Do all the things!
 *
 **/

// Primary functions
#include "app.hpp"

// System libs
#include "pico/multicore.h"
#include "hardware/irq.h"

int main()
{
    sleep_ms(10);

    Application::GetInstance();
    multicore_launch_core1(Application::LogicTask);
    Application::UITask();

    return 0;
}

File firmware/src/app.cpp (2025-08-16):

#include "app.hpp"

// General utilites
#include "bitmaps.hpp"
#include "pins.h"
#include "proj.h"

// Primary functions
#include "logic.hpp"

// System libs
#include "hardware/clocks.h"
#include "hardware/gpio.h"
#include "hardware/vreg.h"
#include "pico/bootrom.h"
#include "pico/stdlib.h"

#include <cstdio>
#include <cstring>
#include <vector>

std::unique_ptr<Application> Application::instance { nullptr };

Application* Application::GetInstance()
{
    if (Application::instance == nullptr) {
        Application::instance = std::make_unique<Application>();
    }
    return Application::instance.get();
}

__attribute__((noreturn)) void Application::LogicTask()
{
    auto self = Application::GetInstance();

    while (true) {
        if (self->hwMode == UserMode::Serial) {
            self->logic->AddressReader(&self->dataQueue, false);
        } else {
            switch (self->app_currentSelect) {

            case ProgramSelect::BusDump: {
                self->logic->AddressReader(&self->dataQueue, self->UseNewRemote(), Logic::AllAddresses);
            } break;

            case ProgramSelect::Port80Reader: {
                self->logic->AddressReader(&self->dataQueue, self->UseNewRemote());
            } break;

            case ProgramSelect::Port84Reader: {
                self->logic->AddressReader(&self->dataQueue, self->UseNewRemote(), 0x84);
            } break;

            case ProgramSelect::Port90Reader: {
                self->logic->AddressReader(&self->dataQueue, self->UseNewRemote(), 0x90);
            } break;

            case ProgramSelect::Port300Reader: {
                self->logic->AddressReader(&self->dataQueue, self->UseNewRemote(), 0x300);
            } break;

            case ProgramSelect::Port378Reader: {
                self->logic->AddressReader(&self->dataQueue, self->UseNewRemote(), 0x378);
            } break;

            case ProgramSelect::VoltageMonitor: {
                self->logic->VoltageMonitor(&self->dataQueue);
            } break;

            default: {
                // do nothing
            } break;
            }
        }
        sleep_ms(150);
    }
}

__attribute__((noreturn)) void Application::UITask()
{
    auto self = Application::GetInstance();

    // Set up GPIO for appropriate keypress handling
    switch (self->hwMode) {
    case UserMode::I2CKeypad: {
        // Initialize button IRQ and debounced key readout routine
        gpio_init(PIN_REMOTE_IRQ_R6);
        gpio_set_dir(PIN_REMOTE_IRQ_R6, GPIO_IN);
        gpio_pull_up(PIN_REMOTE_IRQ_R6);
    } break;

    case UserMode::GPIOKeypad: {
        // Initialize button GPIOs and key handler routine
        // Buttons are active low, so enable internal pull-ups
        uint pins[] = { PIN_KEY_UP_R5, PIN_KEY_DOWN_R5, PIN_KEY_SELECT_R5 };
        for (const uint pin : pins) {
            gpio_init(pin);
            gpio_set_dir(pin, GPIO_IN);
            gpio_pull_up(pin);
        }
    } break;

    default: {
        // no keystrokes expected in this mode
    } break;
    }

    // Start UI loop
    while (true) {
        // Read keystrokes
        if (self->UseNewRemote()) {
            self->PollI2CKeypad();
        } else if (self->hwMode == UserMode::GPIOKeypad) {
            // TODO self->PollGPIOKeypad();
        }

        // Handle pending keystrokes
        if (self->keyboard.debounceStage == DebouncerStep::PendingEvent) {
            self->lastActivityTimer = time_us_64();
            self->Keystroke();
        }

        // Output data for user
        self->UserOutput();

        if (self->hwMode != UserMode::Serial) {
            self->StandbyTick();
        }
    }
}

void Application::PollI2CKeypad()
{
    switch (this->keyboard.debounceStage) {

    case DebouncerStep::Poll: {
        if (time_us_64() >= this->keyboard.nextPoll) {
            bool hwIrqPending = !gpio_get(PIN_REMOTE_IRQ_R6);
            if (hwIrqPending) {
                this->keyboard.irqFlagPoll = this->hw_gpioexp->GetInterruptCapture();
                this->keyboard.debounceExpiry = time_us_64() + Application::c_debounceRate;
                this->keyboard.debounceStage = DebouncerStep::FirstTrigger;
            }
            this->keyboard.nextPoll = time_us_64() + 50000;
        }
    } break;

    case DebouncerStep::FirstTrigger: {
        if (time_us_64() >= this->keyboard.debounceExpiry) {
            uint8_t currentKeymap = this->hw_gpioexp->GetAll(); // This clears the hw interrupt
            uint8_t persistentPress = (this->keyboard.irqFlagPoll & currentKeymap);
            this->keyboard.debounceStage = DebouncerStep::Poll;
            if (persistentPress != this->keyboard.previousPress) {
                if (persistentPress & (1 << GPIOEXP_KEY_UP)) {
                    this->keyboard.current |= KE_Up;
                }
                if (persistentPress & (1 << GPIOEXP_KEY_DOWN)) {
                    this->keyboard.current |= KE_Down;
                }
                if (persistentPress & (1 << GPIOEXP_KEY_SELECT)) {
                    this->keyboard.current |= KE_Select;
                }
                if (persistentPress & (1 << GPIOEXP_KEY_BACK)) {
                    this->keyboard.current |= KE_Back;
                }
                if (this->keyboard.current != KE_None) {
                    this->keyboard.debounceStage = DebouncerStep::PendingEvent;
                }
            }
            this->keyboard.previousPress = persistentPress;
            this->keyboard.irqFlagPoll = 0x00;
            this->keyboard.debounceExpiry = 0;
        }
    } break;

    default: {
        // Wait for an external event to reset the key poll state
    } break;
    }
}
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

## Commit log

2022-06-17 initial file commit
    [ISA card rev1.kicad_pcb, ISA card rev1.kicad_sch]
2022-06-17 rev 2 ISA board
    [ISA card rev2.kicad_pcb, ISA card rev2.kicad_sch]
2022-06-18 more available 74LVC02 footprint; generate gbrs
    [ISA card rev2-B_Cu.gbr, ISA card rev2-B_Mask.gbr, ISA card rev2-B_Paste.gbr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]
2022-06-20 rev4 board
    [ISA card rev2-B_Cu.gbr, ISA card rev2-B_Mask.gbr, ISA card rev2-B_Paste.gbr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]
2022-10-23 Switched to a 128x32 display by default
2022-11-12 PCB revision 5
    [ISA rev4-B_Cu.gbr, ISA rev4-B_Mask.gbr, ISA rev4-B_Paste.gbr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]
2022-11-14 PCB rev 5.1
    [ISA rev5-B_Cu.gbr, ISA rev5-B_Mask.gbr, ISA rev5-B_Paste.gbr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]
2022-12-03 GPIO was the wrong approach - Removed the GPIO-based ISA bus handler library. Way too slow! - Brand new PIO-based read logic. Wicked fast!
    Smarter application handling
    - Provisioning for logic plugin selection
    - Implemented multi-core, queued serial print for Port 80h readout
2022-12-04 Registering reset events - Implemented reset status polling with the 2nd PIO instance - Recording timestamp since last reset, with microseconds precision. Prints in milliseconds.
2022-12-04 Implemented voltage monitoring - Reads 5V and 12V and prints to serial every 100ms - Precision is not really there. Use CALIB variables in CMake config for crude static adjustment.
2022-12-05 OLED is displaying things! - Trashed old DIY OLED library - Added submodule for SSD1306 library - May add compatibility for SH1106 in the future - This library is C++... Renamed main.c so compiler do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
    [main.cpp]
2022-12-06 Better port 80h experience - Keep track of the last 4 events - Better displaying of reset event - Don't stall out after 3 consecutive resets - Remove spurious reset PIO IRQ
    [main.cpp]
2022-12-08 OLED & buttons UI - Split logic and UI operations into dedicated files - Implemented menu for selecting wanted working mode - Up+Down returns to menu - TODO: lost bus reset event!?!? - Converted ever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
    [logic.cpp, main.cpp]
2023-01-01 PCB rev6
    [ISA rev6-B_Cu.gbr, ISA rev6-B_Mask.gbr, ISA rev6-B_Paste.gbr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]
2023-01-01 PCB rev 6 part deux
    [ISA rev6.kicad_pcb, remote.kicad_pcb, remote.kicad_sch]
2023-01-02 final tweaks to rev6?
    [remote.kicad_pcb]
2023-01-02 [firmware] PCB v6 compatibility + QoL improvements - Added MCP23009 library - Naive PCB rev detection. If MCP23009 not found, assume it's v5. - If OLED not detected, wait for USB CDC to come up, then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
    [logic.cpp, main.cpp]
2023-01-02 final rev6 release
    [ISA rev6-B_Cu.gbr, ISA rev6-B_Mask.gbr, ISA rev6-B_Paste.gbr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]
2023-01-02 [firmware] Fixed slightly broken key combos
    [main.cpp]
2023-01-05 [firmware] New features and improvements - Implemented 84h, 90h, 300h and 378h readers - Using contextual menu a bit better - Provisioning for -12V rail monitoring - Custom pages for 128x32 and 128x6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
2023-01-15 [firmware] Testing on rev 6 hw - Redone main entrypoint and basic multicore logic as C++ class - Improved UI and keypad handling - Updated MCP pin and registers definitions - Simplified MCP discovery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
    [app.cpp, logic.cpp, main.cpp]
2023-03-01 Updated PDF schematic for rev6 - Now has both interface board and remote (still wrong wiring tho)
2023-03-01 [pcb] Fixed pinout mistake on remote connector
    [remote.kicad_pcb, remote.kicad_sch]
2023-03-01 Rev7 (final?) PCB
    [ISA rev7-B_Cu.gbr, ISA rev7-B_Mask.gbr, ISA rev7-B_Paste.gbr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]
2023-03-02 rev7 schematic pdfs
2023-03-31 Finalized rev7 including gerbers
    [ISA rev7-B_Cu.gbr, ISA rev7-B_Mask.gbr, ISA rev7-B_Paste.gbr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]
2023-04-25 [firmware] Now with 50% less suckiness - Fixing code style after a pass in SonarLint - Using scoped enumerations where it makes sense - Marked noreturn functions as such - (Temporarily?) Removed supp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
    [app.cpp, logic.cpp, main.cpp]
2023-04-29 [firmware] It lives! - Removed hard-wired SDK path from CMake rules. Use environment variables instead - Added handy jump-to-bootloader menu item - Swapped tasks to other core, so UI is on core0 and 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
    [app.cpp, logic.cpp, main.cpp]
2023-05-01 [firmware] Extra bling! - Bumped patch number, version 0.4.1 - Added PicoPOST bitmap drawing from official documentation as landing Info banner - Retouched icon drawing logic so it's a bit more flexi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
    [app.cpp, logic.cpp]
2023-05-02 [firmware] Bells & whistles - OLED now smoothly dims after 15 seconds of inactivity - Timing set at compile time with CMake define - Fixed crash on reader exit due to double PIO abort trigger - Reset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
    [app.cpp, logic.cpp]
2023-05-05 [firmware] Make 'em toasters fly! - Added simple 3-frame Flying Toasters! sprite and motion pattern - Screen ALWAYS dims after 15s of inactivity (from user and from inputs) - When in menu, switch to 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
2023-08-27 [firmware] Brain got tired with -12V input - Spice simulations suggest a mostly linear correlation in the active ADC range for our -12V solution - Using more precise and clearer coefficients in volta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
2023-12-27 [firmware] First ugly attempt at getting reset pulse to work again
    [logic.cpp]
2023-12-27 [firmware] Reset detect works and bus read has been restored! - Bumped firmware to revision 0.5.0 - TODO: HW needs a minor fix to include IOCHRDY to the read trigger logic - Added queue data flag for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
    [app.cpp, logic.cpp]
2023-12-28 [firmware] Added a few NOPs to let bus transcievers settle down during address bank switching
2023-12-28 [firmware] Figuring out address byte mangling and missing data - In fast transaction bursts, we are missing some data because the PIO stalls, after filling the 8 FIFO buffers with no one emptying the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
    [app.cpp, logic.cpp]
2024-01-16 ISA rev8 preliminary
    [ISA rev8-B_Cu.gbr, ISA rev8-B_Mask.gbr, ISA rev8-B_Paste.gbr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]
2024-01-21 [firmware] Partially matching PCB rev 8 - Removed -12V reader. It will never work right :woeisme: - Undoing VCF edits
2024-01-21 rev8 PCB final?
    [ISA rev8-B_Cu.gbr, ISA rev8-B_Mask.gbr, ISA rev8-B_Paste.gbr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]
2025-03-22 [firmware] Dropped -12V readout, it just doesn't work
    [app.cpp, logic.cpp]
2025-03-22 [firmware] WIP - DOES NOT WORK - Try to use DMA to avoid stalling PIO if logic can't dispatch codes fast enough
    [logic.cpp, main.cpp]
2025-08-06 [firmware] Updated layout to make use of official Raspberry Pi Pico VSCode extension
2025-08-06 [firmware] It didn't need DMA, after all - Dropped all references to DMA setup - Also dropped all references to mutex experiment - Temporarily disabled reset pulse reader - Use PIO FIFO IRQ to quickl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
    [app.cpp, logic.cpp, main.cpp]
2025-08-07 [firmware] Added back reset pulse detection via ISR - Split bus reader ISRs between address-filtered and unfiltered acquisition
    [logic.cpp]
2025-08-07 [firmware] Fixed weird memory leak with old-school array, replaced by std::vector
    [app.cpp]
2025-08-07 [firmware] Fixed hang when exiting and re-entering bus readers
    [logic.cpp]
2025-08-07 [firmware] Fixed mode change never working due to exit request flag always stuck active at all times
    [logic.cpp]
2025-08-10 [firmware] Actually fixed unstable operation due to misconfigured overclocking - Just definitions are not enough, we need to inject our own board definition to correctly configure SPI flash clock div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
    [app.cpp]
2025-08-16 preliminary Pro design files
    [Pro rev1.kicad_pcb, Pro rev1.kicad_sch, RP2350A-QFN60.step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]
2025-08-24 updates and fixes to Pro rev1 PCB, possibly prod-ready?
    [1040310811.stp, 470804001.stp, Pro rev1.kicad_pcb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]
